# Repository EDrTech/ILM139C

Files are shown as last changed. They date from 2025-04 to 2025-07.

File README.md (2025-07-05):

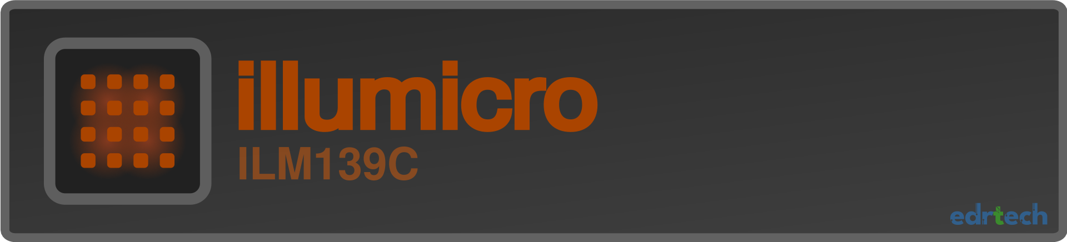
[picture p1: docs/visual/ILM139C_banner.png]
Banner

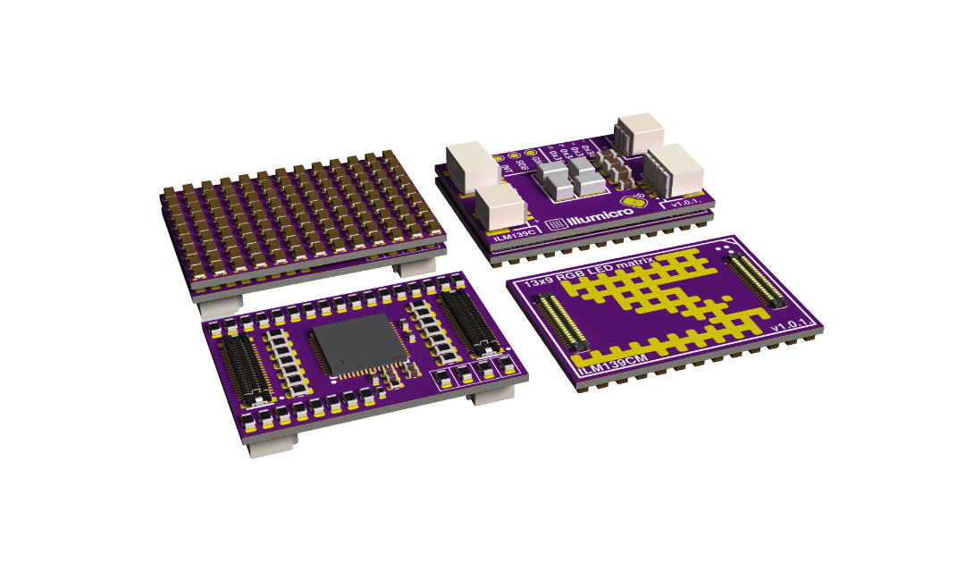
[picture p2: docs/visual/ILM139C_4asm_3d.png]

&nbsp;
###### <sub>Quick access</sub>
---------------------------------------------------------------------------------

<p align="center">
  
  
  
  
</p>

---------------------------------------------------------------------------------
&nbsp;
&nbsp;
&nbsp;
---------------------------------------------------------------------------------
> [!WARNING]
> <p>
> This project is currently under active development. It is experimental, and may not function as intended. The source files might not exactly match tested hardware if you can see this message. Use at your own risk.
><br clear="right"/>
></p>

---------------------------------------------------------------------------------
# Illumicro ILM139C 13x9 RGB LED matrix

<p align="center">
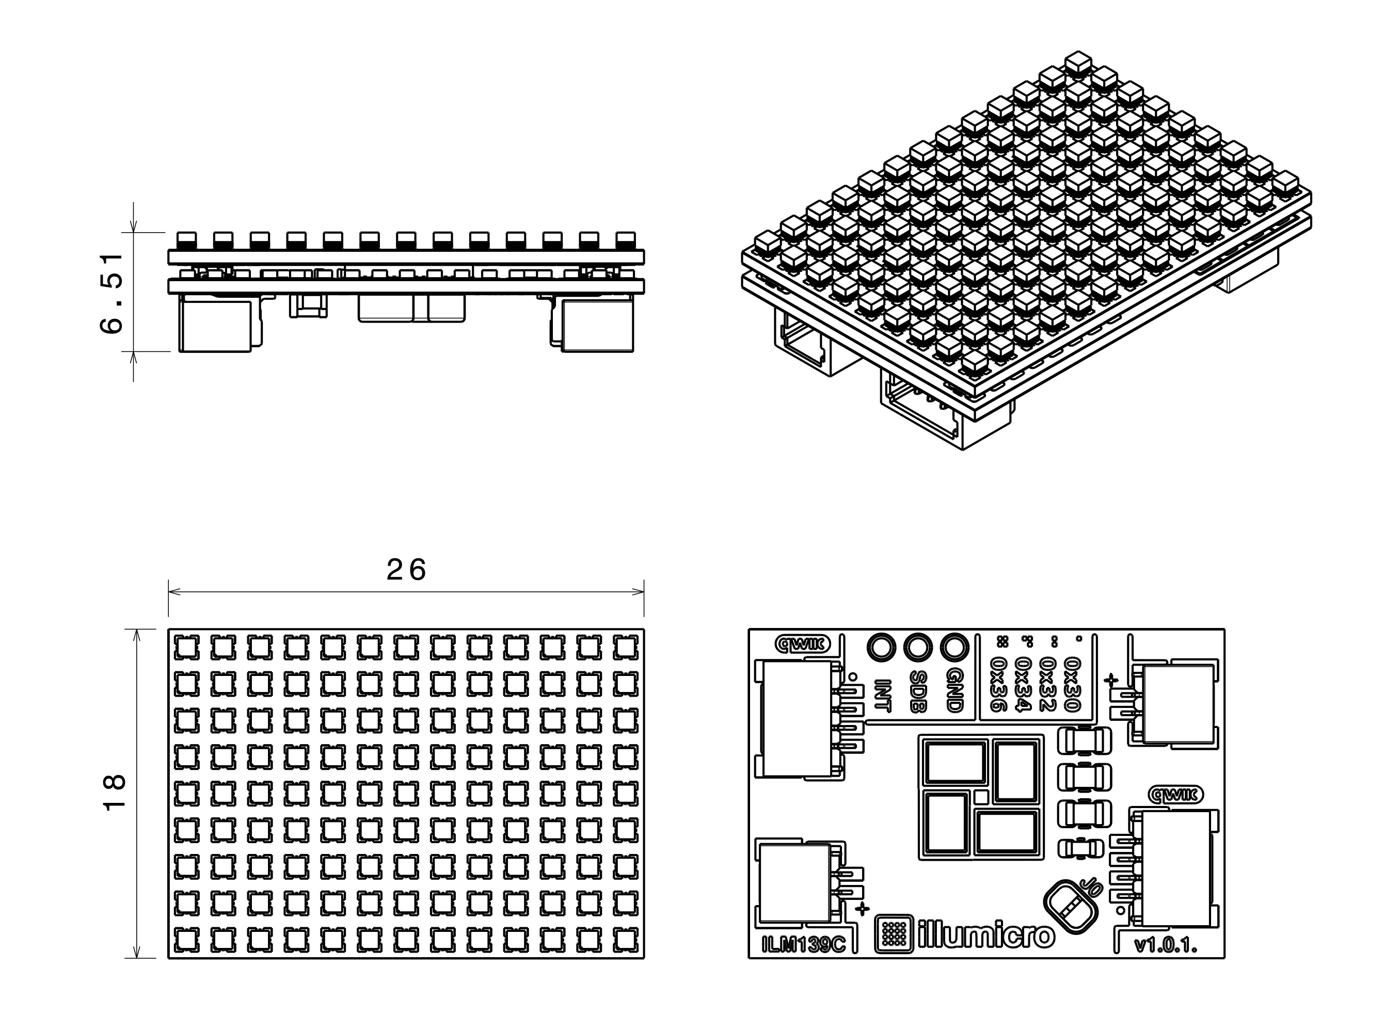
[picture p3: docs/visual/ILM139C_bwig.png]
  
</p>
ILM139C Is an RGB LED module with a matrix of 13x9 RGB LEDs.
It is based on the IS31FL3741A LED matrix driver, which provides an i2c interface for full control of
individual LEDs which is accessible with a standard QWIIC connector. 
QWIIC Connector allows for up to 4 modules to be connected together on a single i2c bus.
Small form factor of 26mm*18mm and 2mm pitch of LEDs allows for creating small 
high density and high brightness displays.

https://github.com/user-attachments/assets/0ada246c-68c4-4b34-9f10-4a2aee3bf7c3

&nbsp;
&nbsp;
&nbsp;
&nbsp;
&nbsp;
&nbsp;
&nbsp;
&nbsp;
&nbsp;
&nbsp;

# Features
&nbsp;
&nbsp;
&nbsp;
&nbsp;
&nbsp;
<p>

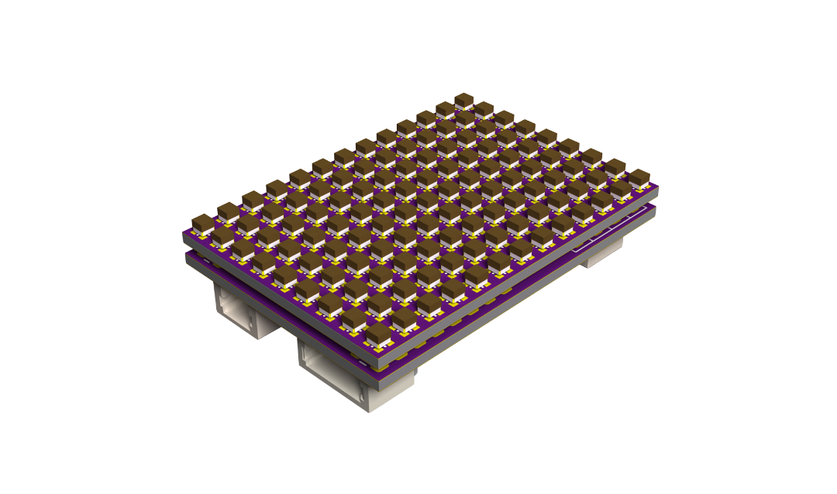
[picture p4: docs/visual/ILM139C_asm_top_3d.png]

  
- Very small footprint of 26mm*18mm
- 13x9 RBG LED matrix
- 1mm*1mm LEDs, with 2mm pitch
- IS31FL3741A Driver
- 2.7V~5.5V Operating voltage
- QWIIC Connector
- Selectable i2c address
- Removable driver/matrix boards
- Separate power supply connector
  
</p>
&nbsp;
&nbsp;
&nbsp;

# ILM139C Module pinout

<p align="center">
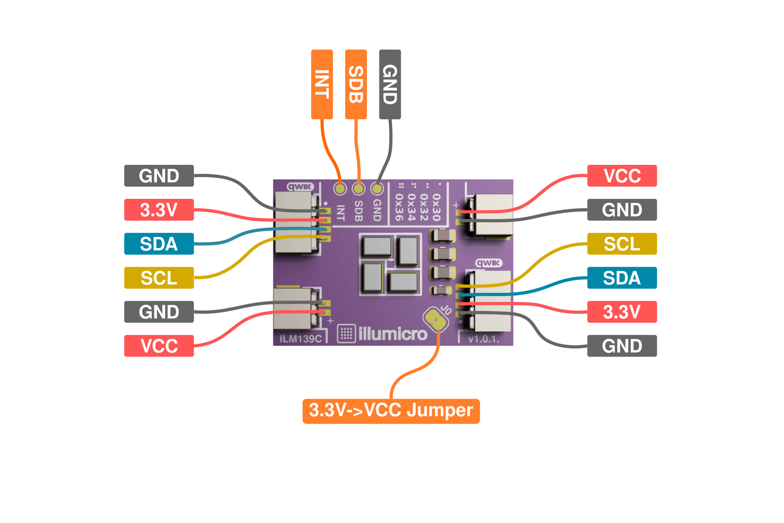
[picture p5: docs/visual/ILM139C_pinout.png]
  
</p>

---------------------------------------------------------------------------------

# Installation and set up

Connect QWIIC cable to one of the available connectors on the bottom of the module. If you want to power the module over QWIIC, the jumper resistor should be soldered on the bottom of the module. If the jumper is present, DO NOT connect external power supply as it will short to 3.3V of the QWIIC!
The module can be programmed over i2c, a library is currently under development to allow straightforward integration with and i2c capable device.

&nbsp;
&nbsp;
&nbsp;

illumicro Series

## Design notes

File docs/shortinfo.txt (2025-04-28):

ILM139C (ILM139CM + ILM139CD) 13X9 RGB LED matrix, 1mm*1mm RGB leds, 2mm pitch, IS31FL3741A driver, compact package 26mm*18mm*3.2mm assembled, 2x qwiic optional connector, 2x power optional connector, i2c address switching using jumper resistors, jumper for qwiic 3v3 to vcc jump, 2.7V-5.5V input voltage, interrupt and shutdown pins broken out, seamlessly stackable design, up to four ILM139C assemblies on single i2c bus, individual LED PWM control, adjustable current, LED open/short software detection, 1MHz i2c, LED matrix is removable, low profile connectors (0.8mm mating height) between matrix and driver boards

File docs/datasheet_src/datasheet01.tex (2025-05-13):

% === START TEMPLATE WITH CONFIGURABLE WATERMARK POSITION ===
\documentclass[10pt]{article}
\usepackage[utf8]{inputenc}
\usepackage[left=50pt,right=50pt,top=100pt,bottom=100pt]{geometry}
\usepackage[T1]{fontenc}
\usepackage{lmodern}
\usepackage[hidelinks]{hyperref}
\usepackage{graphicx}
\usepackage[table]{xcolor}
\usepackage{transparent}
\usepackage{tabularx}
\usepackage{stackengine}
\usepackage{mwe}
\usepackage{tocloft}
\usepackage[hypcap=false,font=small]{caption}
\usepackage{capt-of}
\usepackage{multicol}
\usepackage{ragged2e}
\usepackage{titlesec}
\usepackage{fancyhdr}
\usepackage{etoolbox}
\usepackage{eso-pic}

% === User-Configurable Variables ===
\newcommand{\ProductName}{ILM139C RGB LED Matrix}
\newcommand{\ProductNameShort}{ILM139C}
\newcommand{\WebsiteLinkText}{www.rudectech.com}
\newcommand{\ReleaseDate}{2025-05-13}
\newcommand{\Revision}{Rev.\ 1.0}

% === Watermark Variables ===
\newcommand{\WatermarkPath}{example-image}
\newcommand{\WatermarkScale}{0}
\newcommand{\WatermarkAngle}{45}
\newcommand{\WatermarkOpacity}{0.1}
\newcommand{\WatermarkPosX}{0.1\paperwidth}
\newcommand{\WatermarkPosY}{0.1\paperheight}

% Place watermark
\AddToShipoutPictureBG{%
	\AtPageLowerLeft{%
		\raisebox{\WatermarkPosY}[0pt][0pt]{%
			\makebox[\WatermarkPosX][l]{%
				\transparent{\WatermarkOpacity}%
				%
			}%
		}%
	}%
}

% TOC config
\renewcommand{\contentsname}{Table of Contents}
\setcounter{tocdepth}{2}
\renewcommand{\cftdotsep}{1.5}
\renewcommand{\cftsecleader}{\cftdotfill{\cftdotsep}}
\renewcommand{\cftsubsecleader}{\cftdotfill{\cftdotsep}}
\setlength{\cftbeforesecskip}{0.5em}
\setlength{\cftbeforesubsecskip}{0.5em}

\renewcommand{\familydefault}{\sfdefault}

\pagestyle{fancy}
\fancyhf{}
\renewcommand{\headrulewidth}{0.4pt}
\renewcommand{\footrulewidth}{0.4pt}
\setlength{\headheight}{60pt}
\setlength{\headsep}{10pt}
\setlength{\footskip}{50pt}
\lhead{}
\rhead{%
	\\[-0.5em]
	{\scriptsize\textcolor{gray!50}{\WebsiteLinkText}}%
}
\fancyfoot[L]{\footnotesize\textcolor{gray!50}{{\ProductNameShort} Datasheet}}%
\fancyfoot[C]{\footnotesize\textcolor{gray!50}{\Revision}}
\fancyfoot[R]{\footnotesize\textcolor{gray!50}{\thepage}}

\fancypagestyle{plain}{%
	\fancyhf{}%
	\lhead{\Large\textbf{\ProductNameShort}}%
	\rhead{%
		\\[-0.5em]
		{\scriptsize\textcolor{gray!50}{\WebsiteLinkText}}%
	}%
\fancyfoot[L]{\footnotesize\textcolor{gray!50}{{\ProductNameShort} Datasheet}}%
	\fancyfoot[C]{\footnotesize\textcolor{gray!50}{\Revision}}%
	\fancyfoot[R]{\footnotesize\textcolor{gray!50}{\thepage}}%
	\renewcommand{\headrulewidth}{0.4pt}%
	\renewcommand{\footrulewidth}{0.4pt}%
}

\setcounter{secnumdepth}{3}
\renewcommand{\thesubsection}{\arabic{section}.\arabic{subsection}}
\renewcommand{\thesubsubsection}{\arabic{section}.\arabic{subsection}.\arabic{subsubsection}}
\titleformat{\subsection}[hang]
{\large\bfseries}{\thesubsection}{1em}{}
[\color{gray!30}\rule{\textwidth}{0.4pt}]
\titlespacing*{\subsection}{0pt}{1.5\baselineskip}{1\baselineskip}
\newcommand{\sectionbreak}{\clearpage}

\begin{document}
	\flushbottom
	\begin{center}
		{\LARGE\bfseries \ProductName\par}
		\vspace{1ex}
		{\normalsize Datasheet\par}
	\end{center}
	\vspace{2\baselineskip}
	
	\noindent
	\begin{minipage}[t]{0.45\textwidth}
		\section{Features}\label{sec:features}
		\vspace{\baselineskip}
		\begin{itemize}
			\item 13x9 RGB LED matrix
			\item Small 26mm*18mm Footprint
			\item 2mm pitch, 1mm x 1mm LEDs
			\item Based on IS31FL3741A LED driver
			\item Individual LED PWM control
			\item 2.7V–5.5V input voltage range
			\item Qwiic-compatible connector
			\item Optional 2-pin power connector
			\item I\textsuperscript{2}C address selection via jumpers
		\end{itemize}
	\end{minipage}
	\hfill
	\begin{minipage}[t]{0.5\textwidth}
		\section{Description}\label{sec:desc}
		\vspace{\baselineskip}
		This compact RGB LED matrix module integrates a high-density 13×9 full-color LED array with an onboard IS31FL3741 driver IC. Designed for seamless integration into I2C-based systems, the module supports individual PWM control of all 351 LEDs and features a robust, stackable form factor suitable for embedded, wearable, and interactive display applications.
		
	\begin{center}
		\vskip 30px
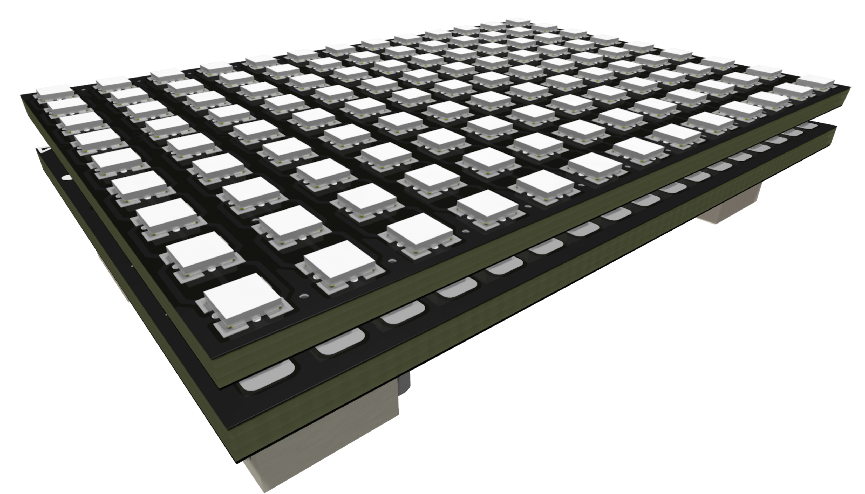
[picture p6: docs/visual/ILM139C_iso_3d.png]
	
	\captionof{figure}{Module Overview}
	\label{fig:component}
\end{center}

	\end{minipage}
	
	\section*{\contentsname}
	\begin{multicols}{2}
		{\let\oldcontentsname\contentsname
			\renewcommand{\contentsname}{}
			\tableofcontents
			\let\contentsname\oldcontentsname}
	\end{multicols}
	
	\vspace{1em}
	\noindent\textbf{Revision History}\par
	\begin{tabularx}{\textwidth}{|l|X|}
		\hline
		\rowcolor{gray!25}\textbf{Date} & \textbf{Description} \\ \hline
		\ReleaseDate & Initial release \\ \hline
	\end{tabularx}
	\captionof{table}{Revision History}\label{tab:rev}
	
	\sectionbreak
	
	\section{Device Overview}\label{sec:overview}
	\subsection{Part Number Options}\label{sec:overview.1}
	\begin{tabularx}{\textwidth}{|X|X|X|}
		\hline
		\rowcolor{gray!25}\textbf{PART NUMBER} & \textbf{PACKAGE} & \textbf{DESCRIPTION} \\ \hline
		ILM139C & 26mm × 18mm × 3.2mm & Complete module \\ \hline
		ILM139CD & Driver board & IS31FL3741A module \\ \hline
		ILM139CM & LED matrix board & 13x9 RGB LED matrix module \\ \hline
	\end{tabularx}
	\captionof{table}{Part Number Options}\label{tab:overview1}
	\sectionbreak
	\subsection{Pin Configuration and Functions}\label{sec:overview.2}
	\begin{tabularx}{\textwidth}{|l|X|}
		\hline
		\rowcolor{gray!25}\textbf{Label} & \textbf{Description} \\ \hline
		SDA & I\textsuperscript{2}C data \\ \hline
		SCL & I\textsuperscript{2}C clock \\ \hline
		INT & Interrupt output \\ \hline
		SDB & Shutdown \\ \hline
		3.3V & QWIIC 3.3V \\ \hline
		VCC & 2.7V~5.5V Power supply input \\ \hline
		GND & Ground \\ \hline
		3.3V->VCC Jumper & 0603 SMD Jumper. If present, VCC=QWIIC 3.3V \\ \hline
	\end{tabularx}
	\captionof{table}{Pin description}\label{tab:rev}
	\begin{center}
		\captionof{figure}{Module Pins}\label{fig:component}
	\end{center}

	\sectionbreak
	
	\section{Specifications}\label{sec:specs}
	\subsection{Absolute Maximum Ratings}\label{sec:specs.1}
	\begin{tabularx}{\textwidth}{|X|X|X|}
		\hline
		\rowcolor{gray!25}\textbf{PARAMETER} & \textbf{MAX RATING} & \textbf{UNIT} \\ \hline
		Supply Voltage (VCC) & 6.0 & V \\ \hline
		Storage Temperature & -40 to 85 & °C \\ \hline
	\end{tabularx}
	\captionof{table}{Absolute Maximum Ratings}\label{tab:amax}
	
	\subsection{Recommended Operating Conditions}\label{sec:specs.2}
	\begin{tabularx}{\textwidth}{|X|X|X|}
		\hline
		\rowcolor{gray!25}\textbf{PARAMETER} & \textbf{TYPICAL} & \textbf{UNIT} \\ \hline
		Input Voltage & 3.3 – 5.0 & V \\ \hline
		Operating Temp. Range & -20 to +70 & °C \\ \hline
	\end{tabularx}
	\captionof{table}{Recommended Operating Conditions}\label{tab:opcond}
	
	\subsection{Electrical Characteristics}\label{sec:specs.3}
	\begin{tabularx}{\textwidth}{|X|X|X|}
		\hline
		\rowcolor{gray!25}\textbf{PARAMETER} & \textbf{TYPICAL} & \textbf{UNIT} \\ \hline
		I\textsuperscript{2}C Clock Rate & 1000 & kHz \\ \hline
		LED Current (adjustable) & 1–30 & mA \\ \hline
	\end{tabularx}
	\captionof{table}{Electrical Characteristics}\label{tab:elec}
	
	\sectionbreak
	
	\section{Feature Description}\label{sec:features_desc}
	\subsection{Modular Construction}
	The ILM139C is split into two boards, simplifying repairs and customization. The LED matrix board can be removed or replaced independently of the driver.
	
	\subsection{Qwiic Interface and Power Options}
	The Qwiic system provides a 4-pin JST-SH connector for quick daisy-chaining of I\textsuperscript{2}C devices. Power is typically supplied via Qwiic (3.3V). A solderable SMD jumper on the back of the driver board connects 3.3V from Qwiic to the VCC rail.
	
	\textbf{Important:} If the jumper is soldered, do not connect another external power supply to the 2-pin VCC/GND connector to avoid damaging the module.
	
	If you wish to use external power (3.3–5V), leave the jumper open and connect a regulated supply to the 2-pin header.
	
	\subsection{LED Control and Flexibility}
	Each LED can be controlled independently for color and brightness. The IS31FL3741A handles PWM, current control, and I\textsuperscript{2}C interfacing. For advanced settings, refer to the \underline{\href{https://www.lumissil.com/assets/pdf/core/IS31FL3741A_DS.pdf}{IS31FL3741A datasheet}}
	
	\sectionbreak
	
	\section{Getting Started}\label{sec:getting}
	\subsection{Using Arduino}
	To use ILM139C with Arduino:
	
	\begin{enumerate}
		\item Connect the Qwiic cable to your controller.
		\item Solder the SMD jumper on the ILM139CD driver board if using Qwiic power.
		\item Install the library: \texttt{https://example.com/ILM139C-Arduino}
		\item Upload the basic example sketch.
	\end{enumerate}
	
	\texttt{
		Wire.begin(); \\
		ILM139C.begin(); \\
		ILM139C.setPixel(5, 3, 255, 0, 0);
	}
	
	\sectionbreak
	
	\section{Part numbering Information}\label{sec:order}
	\begin{tabularx}{\textwidth}{|X|X|X|}
		\hline
		\rowcolor{gray!25}\textbf{PART NUMBER} & \textbf{ORDER CODE} & \textbf{DESCRIPTION} \\ \hline
		ILM139C & ILM139C-BASE & Full RGB Matrix Module \\ \hline
		ILM139CD & ILM139C-DRV & Driver Moduleonly \\ \hline
		ILM139CM & ILM139C-MTX & LED Matrix only \\ \hline
	\end{tabularx}
	\captionof{table}{Ordering Information}\label{tab:order}
	
\end{document}

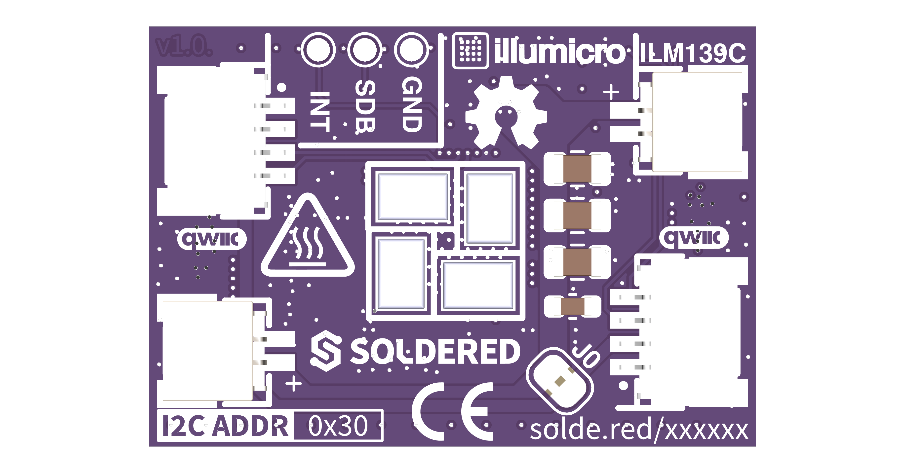
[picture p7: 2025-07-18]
pcb_src/v1.0.0/ILM139C_driver/ILM139CM_designp.png

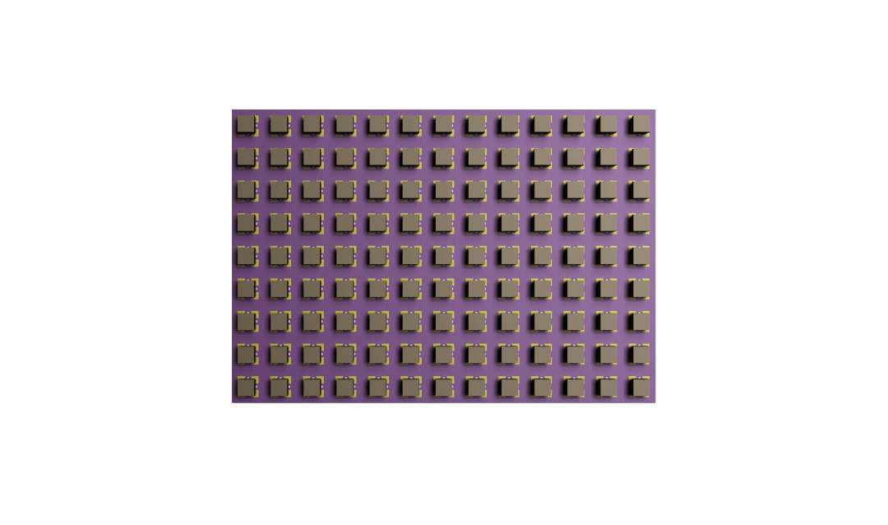
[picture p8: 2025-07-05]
docs/visual/ILM139C_top.png

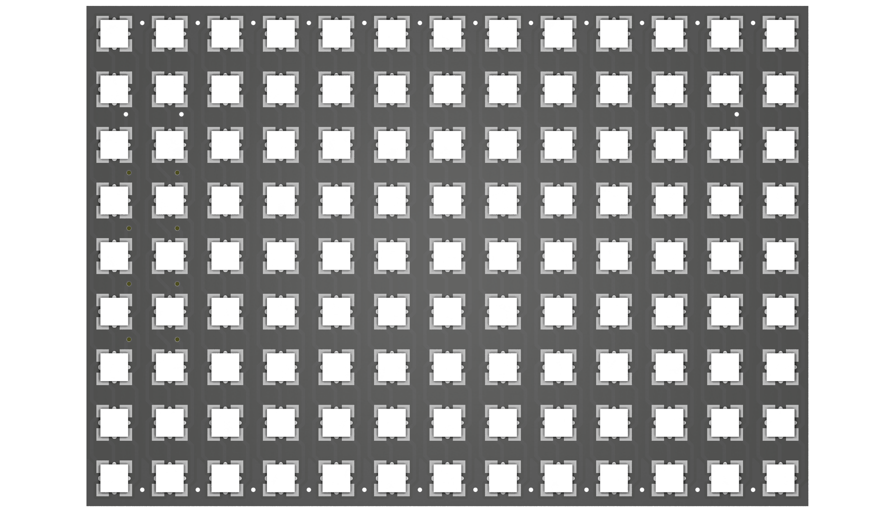
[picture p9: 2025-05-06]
docs/visual/ILM139CM_top.png

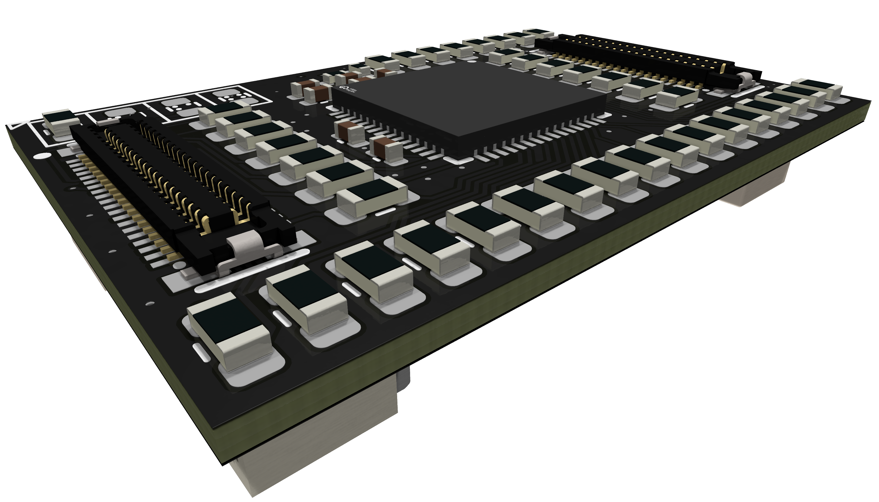
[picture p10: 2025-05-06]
docs/visual/ILM139CD_iso_3d_top.png

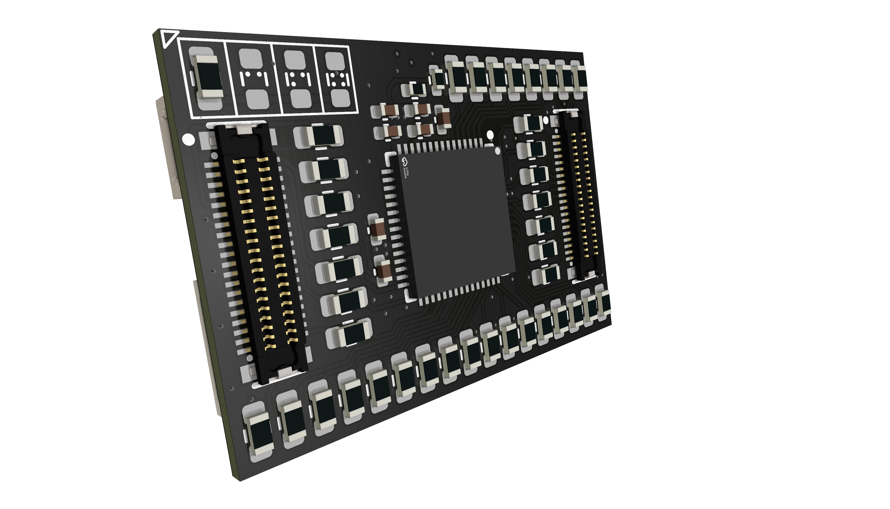
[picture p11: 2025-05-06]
docs/visual/ILM139CD_vert_3d_top.png

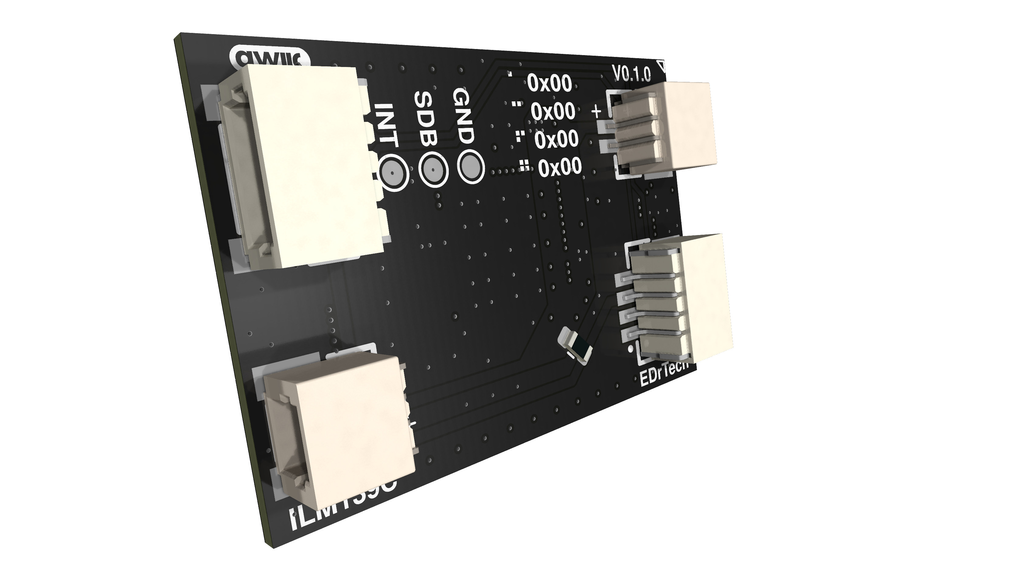
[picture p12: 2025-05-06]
docs/visual/ILM139CD_vert_3d_bot.png

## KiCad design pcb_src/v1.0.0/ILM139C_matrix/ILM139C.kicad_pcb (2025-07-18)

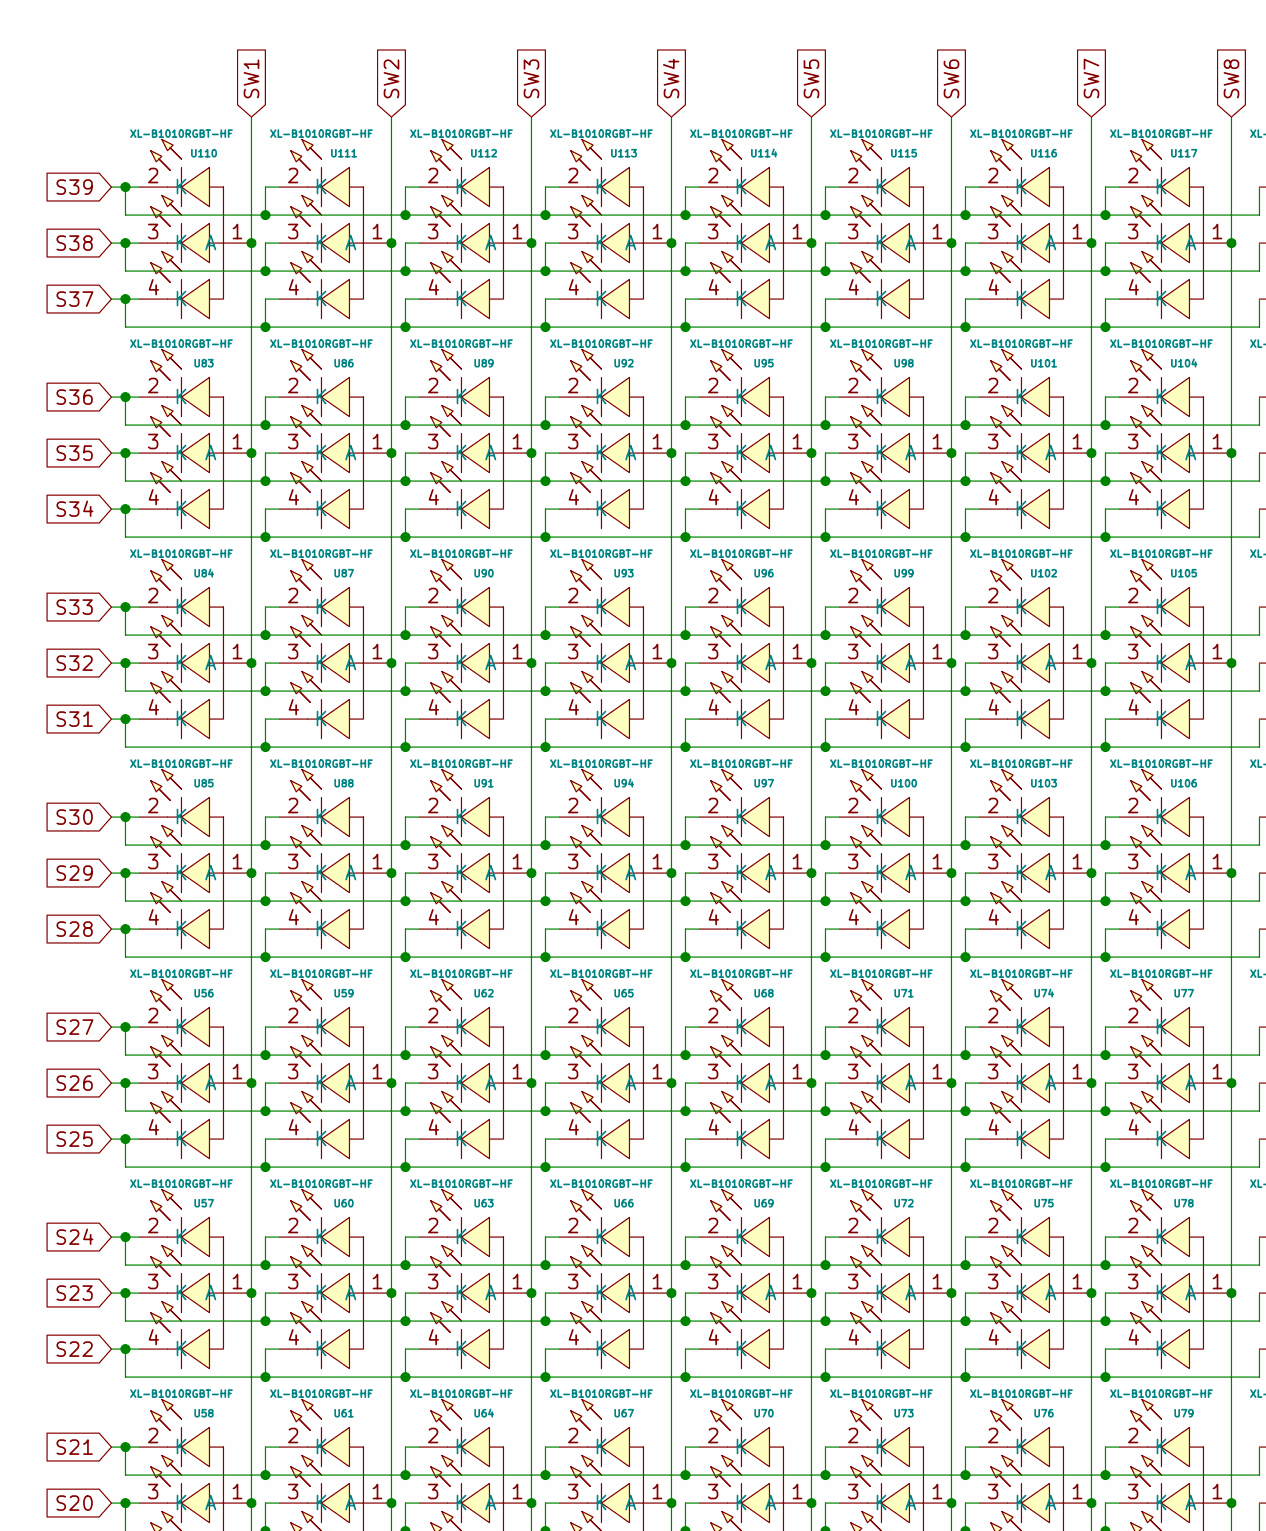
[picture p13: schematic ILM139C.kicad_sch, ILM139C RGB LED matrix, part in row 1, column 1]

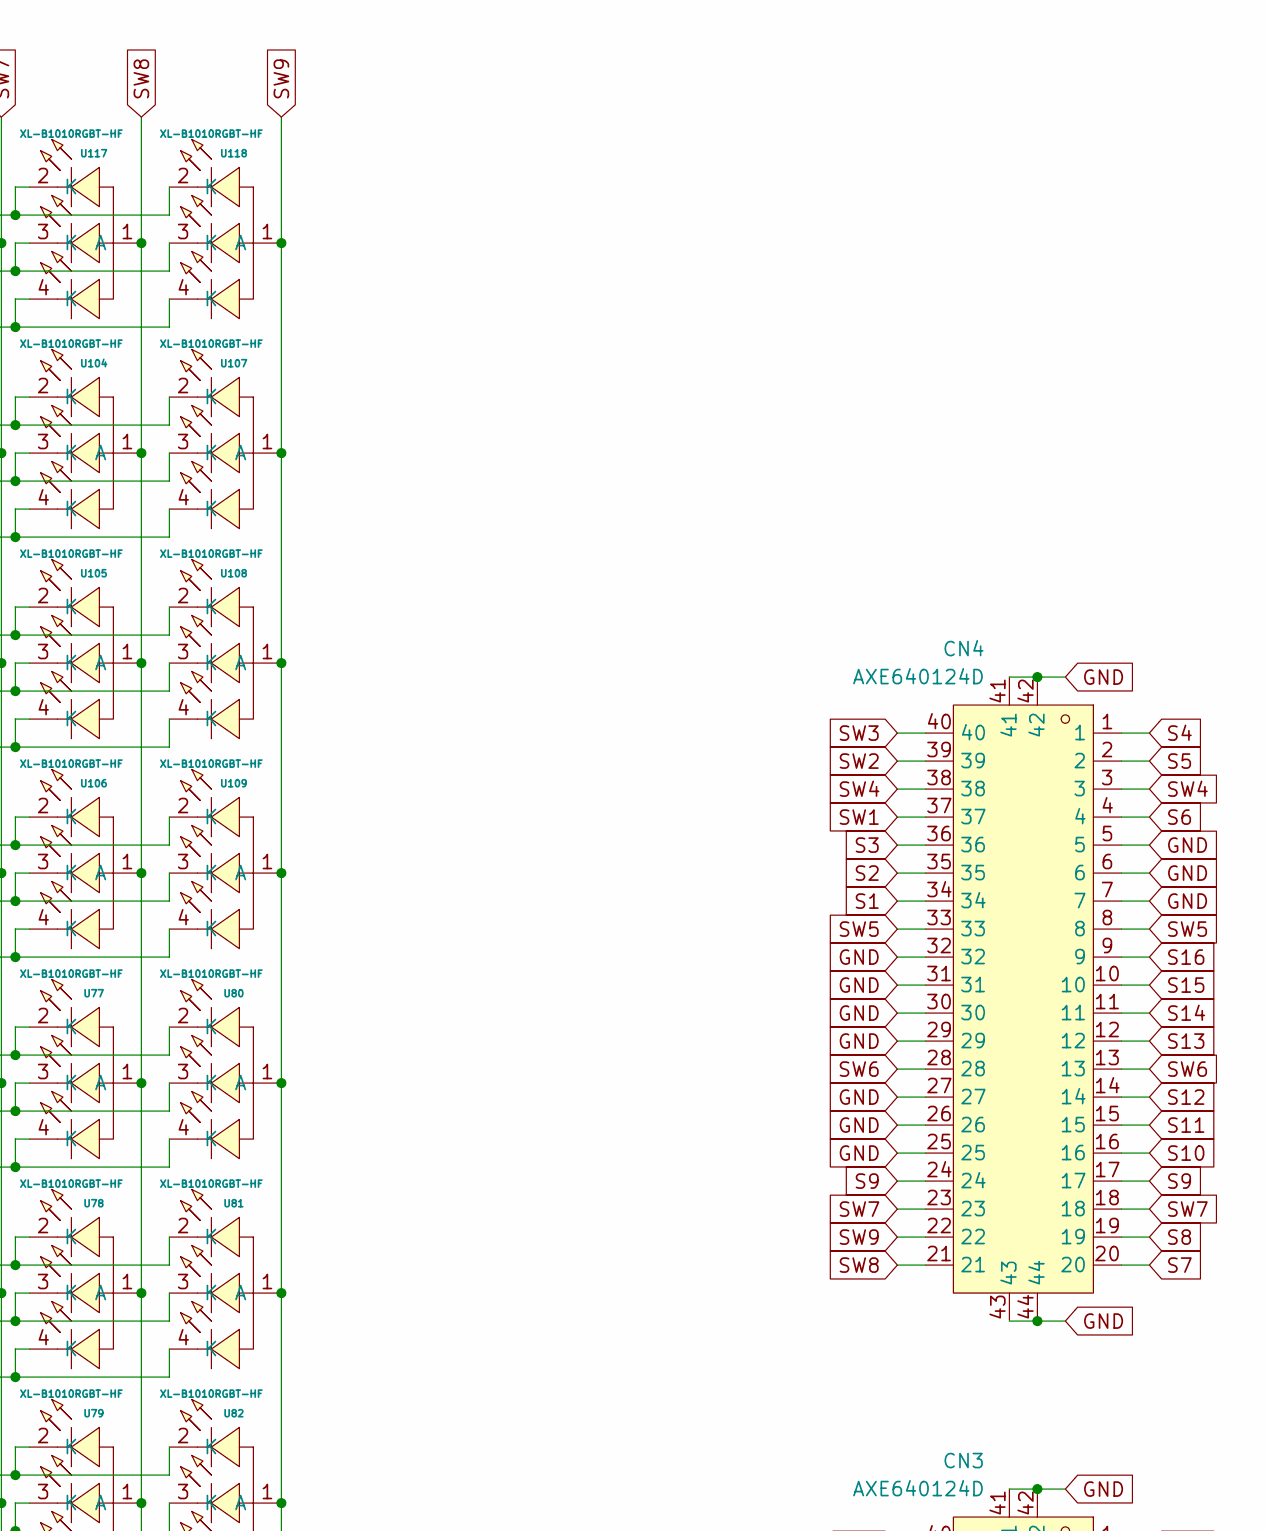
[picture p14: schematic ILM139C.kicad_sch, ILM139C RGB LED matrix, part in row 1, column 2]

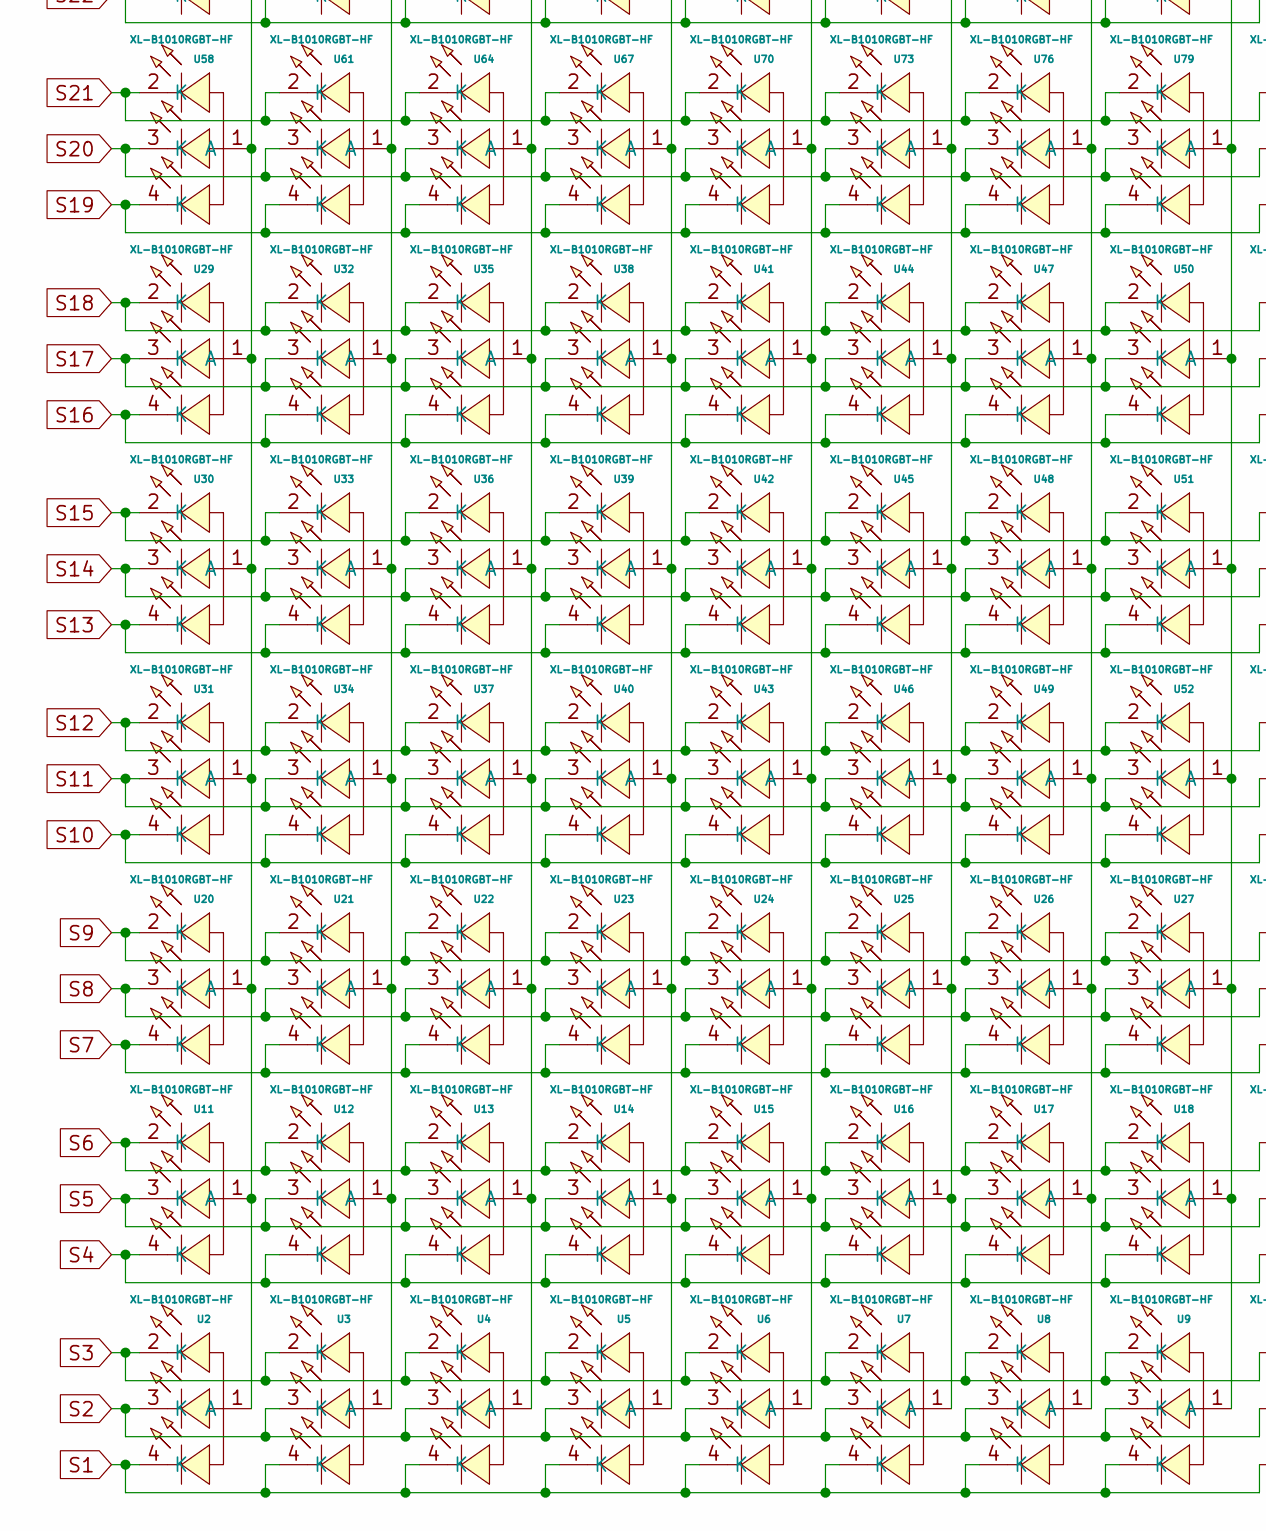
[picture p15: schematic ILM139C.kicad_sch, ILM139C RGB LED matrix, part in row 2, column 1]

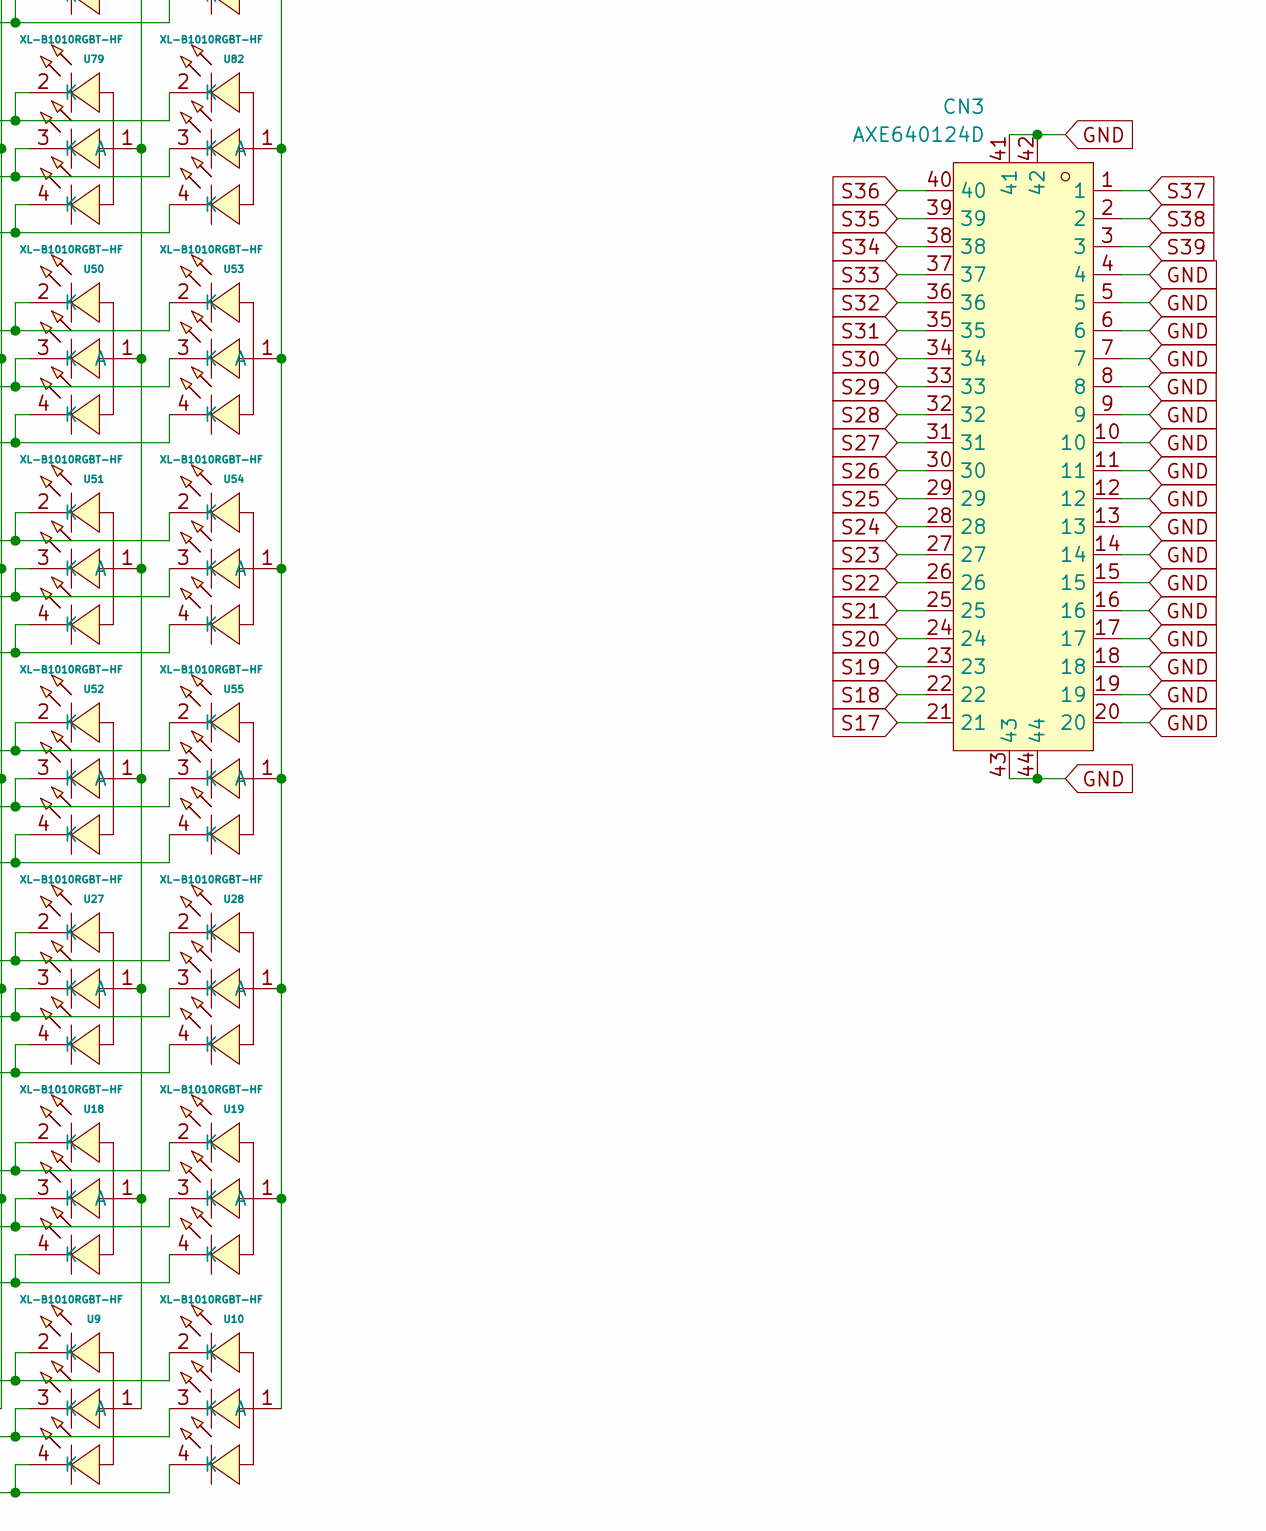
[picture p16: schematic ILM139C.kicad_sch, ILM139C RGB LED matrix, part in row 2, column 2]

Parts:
CN3, CN4: AXE640124D; CONN-SMD_40P-P0.40_OK-14GM040-04; LCSC Part C5128265
U2, U3, U4, U5, U6, U7, U8, U9, U10, U11, U12, U13, U14, U15, U16, U17, U18, U19, U20, U21, U22, U23, U24, U25, U26, U27, U28, U29, U30, U31, U32, U33, U34, U35, U36, U37, U38, U39, U40, U41, U42, U43, U44, U45, U46, U47, U48, U49, U50, U51, U52, U53, U54, U55, U56, U57, U58, U59, U60, U61, U62, U63, U64, U65, U66, U67, U68, U69, U70, U71, U72, U73, U74, U75, U76, U77, U78, U79, U80, U81, U82, U83, U84, U85, U86, U87, U88, U89, U90, U91, U92, U93, U94, U95, U96, U97, U98, U99, U100, U101, U102, U103, U104, U105, U106, U107, U108, U109, U110, U111, U112, U113, U114, U115, U116, U117, U118: XL-B1010RGBT-HF; LED-SMD_4P-L1.0-W1.0-TR_1; LCSC Part C22464515

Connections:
GND: CN3.4, CN3.5, CN3.6, CN3.7, CN3.8, CN3.9, CN3.10, CN3.11, CN3.12, CN3.13, CN3.14, CN3.15, CN3.16, CN3.17, CN3.18, CN3.19, CN3.20, CN3.41, CN3.42, CN3.43, CN3.44, CN4.5, CN4.6, CN4.7, CN4.25, CN4.26, CN4.27, CN4.29, CN4.30, CN4.31, CN4.32, CN4.41, CN4.42, CN4.43, CN4.44
S1: CN4.34, U2.4 (K), U3.4 (K), U4.4 (K), U5.4 (K), U6.4 (K), U7.4 (K), U8.4 (K), U9.4 (K), U10.4 (K)
S2: CN4.35, U2.3 (K), U3.3 (K), U4.3 (K), U5.3 (K), U6.3 (K), U7.3 (K), U8.3 (K), U9.3 (K), U10.3 (K)
S3: CN4.36, U2.2 (K), U3.2 (K), U4.2 (K), U5.2 (K), U6.2 (K), U7.2 (K), U8.2 (K), U9.2 (K), U10.2 (K)
S4: CN4.1, U11.4 (K), U12.4 (K), U13.4 (K), U14.4 (K), U15.4 (K), U16.4 (K), U17.4 (K), U18.4 (K), U19.4 (K)
S5: CN4.2, U11.3 (K), U12.3 (K), U13.3 (K), U14.3 (K), U15.3 (K), U16.3 (K), U17.3 (K), U18.3 (K), U19.3 (K)
S6: CN4.4, U11.2 (K), U12.2 (K), U13.2 (K), U14.2 (K), U15.2 (K), U16.2 (K), U17.2 (K), U18.2 (K), U19.2 (K)
S7: CN4.20, U20.4 (K), U21.4 (K), U22.4 (K), U23.4 (K), U24.4 (K), U25.4 (K), U26.4 (K), U27.4 (K), U28.4 (K)
S8: CN4.19, U20.3 (K), U21.3 (K), U22.3 (K), U23.3 (K), U24.3 (K), U25.3 (K), U26.3 (K), U27.3 (K), U28.3 (K)
S9: CN4.17, CN4.24, U20.2 (K), U21.2 (K), U22.2 (K), U23.2 (K), U24.2 (K), U25.2 (K), U26.2 (K), U27.2 (K), U28.2 (K)
S10: CN4.16, U31.4 (K), U34.4 (K), U37.4 (K), U40.4 (K), U43.4 (K), U46.4 (K), U49.4 (K), U52.4 (K), U55.4 (K)
S11: CN4.15, U31.3 (K), U34.3 (K), U37.3 (K), U40.3 (K), U43.3 (K), U46.3 (K), U49.3 (K), U52.3 (K), U55.3 (K)
S12: CN4.14, U31.2 (K), U34.2 (K), U37.2 (K), U40.2 (K), U43.2 (K), U46.2 (K), U49.2 (K), U52.2 (K), U55.2 (K)
S13: CN4.12, U30.4 (K), U33.4 (K), U36.4 (K), U39.4 (K), U42.4 (K), U45.4 (K), U48.4 (K), U51.4 (K), U54.4 (K)
S14: CN4.11, U30.3 (K), U33.3 (K), U36.3 (K), U39.3 (K), U42.3 (K), U45.3 (K), U48.3 (K), U51.3 (K), U54.3 (K)
S15: CN4.10, U30.2 (K), U33.2 (K), U36.2 (K), U39.2 (K), U42.2 (K), U45.2 (K), U48.2 (K), U51.2 (K), U54.2 (K)
S16: CN4.9, U29.4 (K), U32.4 (K), U35.4 (K), U38.4 (K), U41.4 (K), U44.4 (K), U47.4 (K), U50.4 (K), U53.4 (K)
S17: CN3.21, U29.3 (K), U32.3 (K), U35.3 (K), U38.3 (K), U41.3 (K), U44.3 (K), U47.3 (K), U50.3 (K), U53.3 (K)
S18: CN3.22, U29.2 (K), U32.2 (K), U35.2 (K), U38.2 (K), U41.2 (K), U44.2 (K), U47.2 (K), U50.2 (K), U53.2 (K)
S19: CN3.23, U58.4 (K), U61.4 (K), U64.4 (K), U67.4 (K), U70.4 (K), U73.4 (K), U76.4 (K), U79.4 (K), U82.4 (K)
S20: CN3.24, U58.3 (K), U61.3 (K), U64.3 (K), U67.3 (K), U70.3 (K), U73.3 (K), U76.3 (K), U79.3 (K), U82.3 (K)
S21: CN3.25, U58.2 (K), U61.2 (K), U64.2 (K), U67.2 (K), U70.2 (K), U73.2 (K), U76.2 (K), U79.2 (K), U82.2 (K)
S22: CN3.26, U57.4 (K), U60.4 (K), U63.4 (K), U66.4 (K), U69.4 (K), U72.4 (K), U75.4 (K), U78.4 (K), U81.4 (K)
S23: CN3.27, U57.3 (K), U60.3 (K), U63.3 (K), U66.3 (K), U69.3 (K), U72.3 (K), U75.3 (K), U78.3 (K), U81.3 (K)
S24: CN3.28, U57.2 (K), U60.2 (K), U63.2 (K), U66.2 (K), U69.2 (K), U72.2 (K), U75.2 (K), U78.2 (K), U81.2 (K)
S25: CN3.29, U56.4 (K), U59.4 (K), U62.4 (K), U65.4 (K), U68.4 (K), U71.4 (K), U74.4 (K), U77.4 (K), U80.4 (K)
S26: CN3.30, U56.3 (K), U59.3 (K), U62.3 (K), U65.3 (K), U68.3 (K), U71.3 (K), U74.3 (K), U77.3 (K), U80.3 (K)
S27: CN3.31, U56.2 (K), U59.2 (K), U62.2 (K), U65.2 (K), U68.2 (K), U71.2 (K), U74.2 (K), U77.2 (K), U80.2 (K)
S28: CN3.32, U85.4 (K), U88.4 (K), U91.4 (K), U94.4 (K), U97.4 (K), U100.4 (K), U103.4 (K), U106.4 (K), U109.4 (K)
S29: CN3.33, U85.3 (K), U88.3 (K), U91.3 (K), U94.3 (K), U97.3 (K), U100.3 (K), U103.3 (K), U106.3 (K), U109.3 (K)
S30: CN3.34, U85.2 (K), U88.2 (K), U91.2 (K), U94.2 (K), U97.2 (K), U100.2 (K), U103.2 (K), U106.2 (K), U109.2 (K)
S31: CN3.35, U84.4 (K), U87.4 (K), U90.4 (K), U93.4 (K), U96.4 (K), U99.4 (K), U102.4 (K), U105.4 (K), U108.4 (K)
S32: CN3.36, U84.3 (K), U87.3 (K), U90.3 (K), U93.3 (K), U96.3 (K), U99.3 (K), U102.3 (K), U105.3 (K), U108.3 (K)
S33: CN3.37, U84.2 (K), U87.2 (K), U90.2 (K), U93.2 (K), U96.2 (K), U99.2 (K), U102.2 (K), U105.2 (K), U108.2 (K)
S34: CN3.38, U83.4 (K), U86.4 (K), U89.4 (K), U92.4 (K), U95.4 (K), U98.4 (K), U101.4 (K), U104.4 (K), U107.4 (K)
S35: CN3.39, U83.3 (K), U86.3 (K), U89.3 (K), U92.3 (K), U95.3 (K), U98.3 (K), U101.3 (K), U104.3 (K), U107.3 (K)
S36: CN3.40, U83.2 (K), U86.2 (K), U89.2 (K), U92.2 (K), U95.2 (K), U98.2 (K), U101.2 (K), U104.2 (K), U107.2 (K)
S37: CN3.1, U110.4 (K), U111.4 (K), U112.4 (K), U113.4 (K), U114.4 (K), U115.4 (K), U116.4 (K), U117.4 (K), U118.4 (K)
S38: CN3.2, U110.3 (K), U111.3 (K), U112.3 (K), U113.3 (K), U114.3 (K), U115.3 (K), U116.3 (K), U117.3 (K), U118.3 (K)
S39: CN3.3, U110.2 (K), U111.2 (K), U112.2 (K), U113.2 (K), U114.2 (K), U115.2 (K), U116.2 (K), U117.2 (K), U118.2 (K)
SW1: CN4.37, U2.1 (A), U11.1 (A), U20.1 (A), U29.1 (A), U30.1 (A), U31.1 (A), U56.1 (A), U57.1 (A), U58.1 (A), U83.1 (A), U84.1 (A), U85.1 (A), U110.1 (A)
SW2: CN4.39, U3.1 (A), U12.1 (A), U21.1 (A), U32.1 (A), U33.1 (A), U34.1 (A), U59.1 (A), U60.1 (A), U61.1 (A), U86.1 (A), U87.1 (A), U88.1 (A), U111.1 (A)
SW3: CN4.40, U4.1 (A), U13.1 (A), U22.1 (A), U35.1 (A), U36.1 (A), U37.1 (A), U62.1 (A), U63.1 (A), U64.1 (A), U89.1 (A), U90.1 (A), U91.1 (A), U112.1 (A)
SW4: CN4.3, CN4.38, U5.1 (A), U14.1 (A), U23.1 (A), U38.1 (A), U39.1 (A), U40.1 (A), U65.1 (A), U66.1 (A), U67.1 (A), U92.1 (A), U93.1 (A), U94.1 (A), U113.1 (A)
SW5: CN4.8, CN4.33, U6.1 (A), U15.1 (A), U24.1 (A), U41.1 (A), U42.1 (A), U43.1 (A), U68.1 (A), U69.1 (A), U70.1 (A), U95.1 (A), U96.1 (A), U97.1 (A), U114.1 (A)
SW6: CN4.13, CN4.28, U7.1 (A), U16.1 (A), U25.1 (A), U44.1 (A), U45.1 (A), U46.1 (A), U71.1 (A), U72.1 (A), U73.1 (A), U98.1 (A), U99.1 (A), U100.1 (A), U115.1 (A)
SW7: CN4.18, CN4.23, U8.1 (A), U17.1 (A), U26.1 (A), U47.1 (A), U48.1 (A), U49.1 (A), U74.1 (A), U75.1 (A), U76.1 (A), U101.1 (A), U102.1 (A), U103.1 (A), U116.1 (A)
SW8: CN4.21, U9.1 (A), U18.1 (A), U27.1 (A), U50.1 (A), U51.1 (A), U52.1 (A), U77.1 (A), U78.1 (A), U79.1 (A), U104.1 (A), U105.1 (A), U106.1 (A), U117.1 (A)
SW9: CN4.22, U10.1 (A), U19.1 (A), U28.1 (A), U53.1 (A), U54.1 (A), U55.1 (A), U80.1 (A), U81.1 (A), U82.1 (A), U107.1 (A), U108.1 (A), U109.1 (A), U118.1 (A)

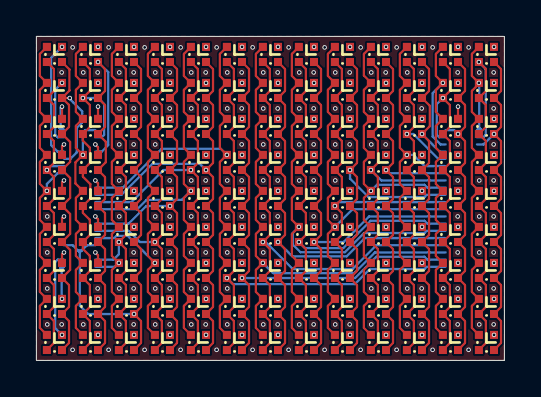
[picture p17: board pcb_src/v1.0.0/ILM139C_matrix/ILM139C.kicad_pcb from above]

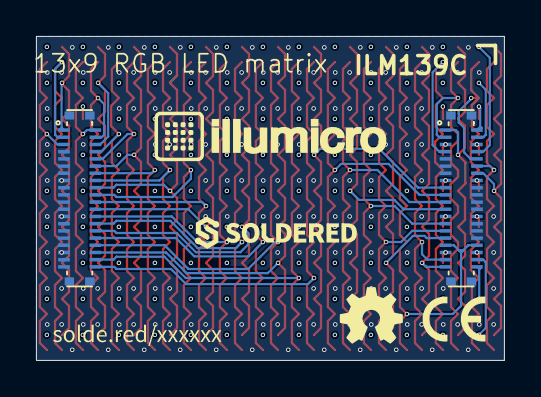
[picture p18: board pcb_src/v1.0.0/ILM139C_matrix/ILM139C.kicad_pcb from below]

Board: 4 copper layers, 26.0 x 18.0 mm, 120 parts (3 on the bottom side), 49 nets.

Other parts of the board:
kibuzzard-68775C53: G***; kibuzzard-68775C53

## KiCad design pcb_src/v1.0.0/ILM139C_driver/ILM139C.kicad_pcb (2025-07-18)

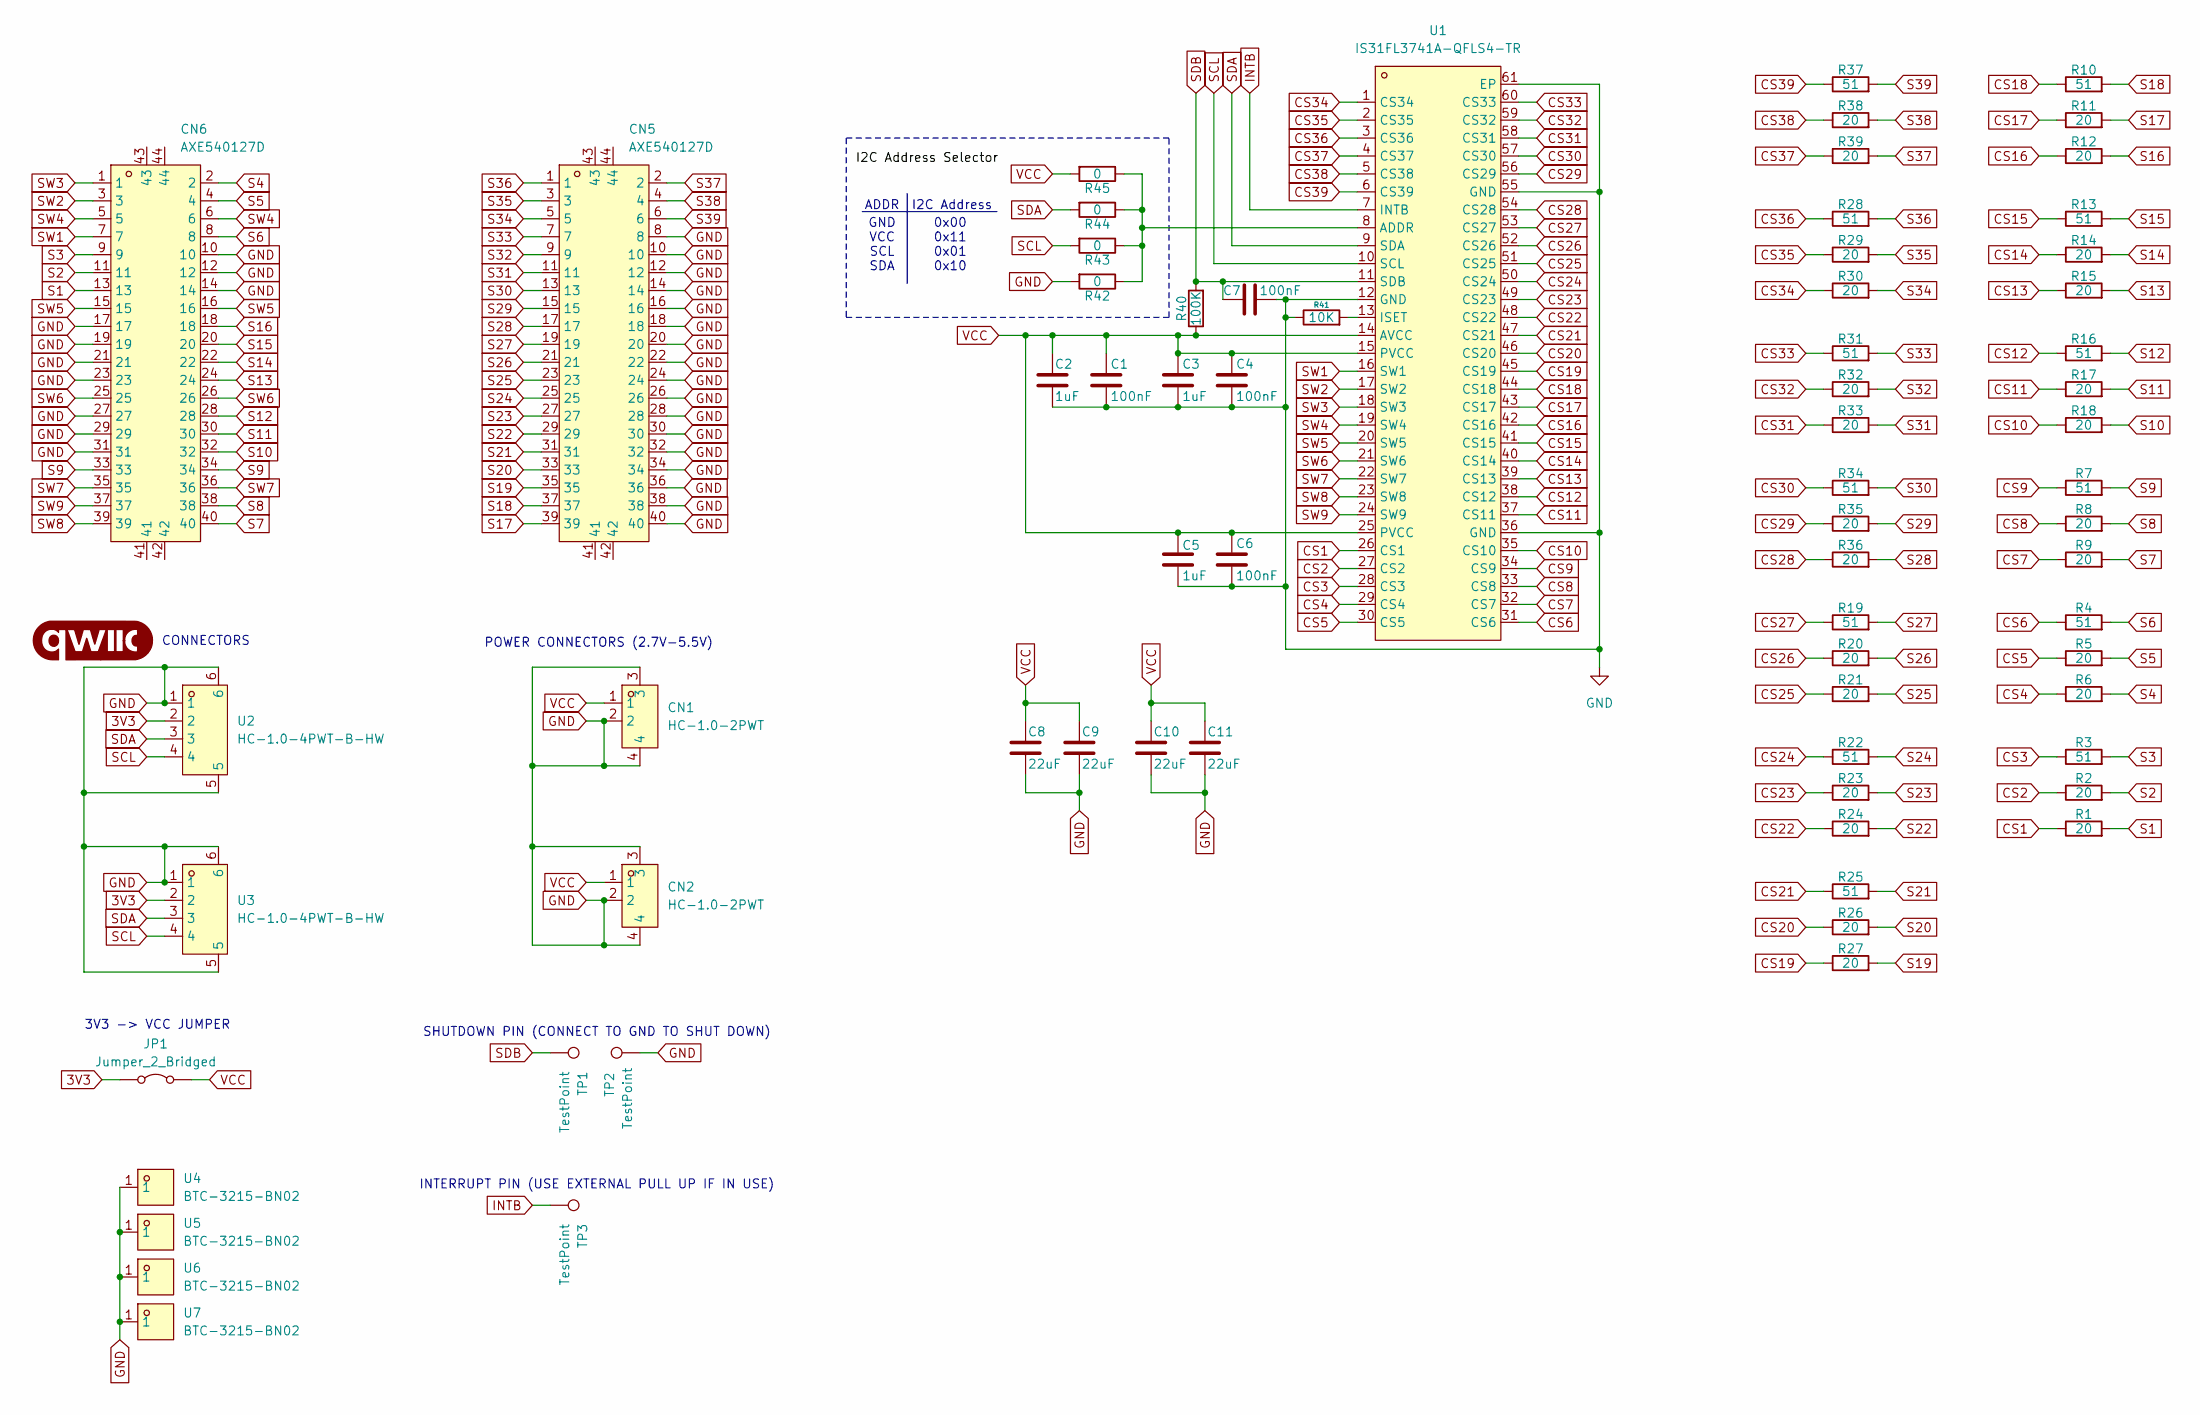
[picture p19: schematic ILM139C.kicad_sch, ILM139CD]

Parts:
C1, C4, C6, C7: 100nF; C_0402_1005Metric
C2, C3, C5: 1uF; C_0402_1005Metric
C8, C9, C10: 22uF; C_0805_2012Metric
C11: 22uF; C_0603_1608Metric
CN1, CN2: HC-1.0-2PWT; CONN-SMD_HC-1.0-2PWT; LCSC Part C2845361
CN5, CN6: AXE540127D; CONN-SMD_40P-P0.40_AXE540127D; LCSC Part C2982234
G1: qwiic_Logo; qwiic_3mm
JP1: Jumper_2_Bridged; SolderJumper-2_P1.3mm_Bridged2Bar_RoundedPad1.0x1.5mm
R1, R2, R5, R6, R8, R9, R11, R12, R14, R15, R17, R18, R20, R21, R23, R24, R26, R27, R29, R30, R32, R33, R35, R36, R38, R39: 20; R_0603_1608Metric
R3, R4, R7, R10, R13, R16, R19, R22, R25, R28, R31, R34, R37: 51; R_0603_1608Metric
R40: 100K; R_0402_1005Metric
R41: 10K; R_0402_1005Metric
R42, R43, R44, R45: 0; R_0603_1608Metric
TP1, TP2, TP3: TestPoint; TestPoint_Pad_D1.0mm
U1: IS31FL3741A-QFLS4-TR; QFN-60_L7.0-W7.0-P0.40-TL-EP5.3; LCSC Part C2940604
U2, U3: HC-1.0-4PWT-B-HW; CONN-SMD_4P-P1.00_HCTL_HC-1.0-4PWT; LCSC Part C19270571
U4, U5, U6, U7: BTC-3215-BN02; SMD-1_L3.0-W2.0-H1.5; LCSC Part C34373670

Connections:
3V3: JP1.1 (A), U2.2, U3.2
CS1: R1.1, U1.26 (CS1)
CS2: R2.1, U1.27 (CS2)
CS3: R3.1, U1.28 (CS3)
CS4: R6.1, U1.29 (CS4)
CS5: R5.1, U1.30 (CS5)
CS6: R4.1, U1.31 (CS6)
CS7: R9.1, U1.32 (CS7)
CS8: R8.1, U1.33 (CS8)
CS9: R7.1, U1.34 (CS9)
CS10: R18.1, U1.35 (CS10)
CS11: R17.1, U1.37 (CS11)
CS12: R16.1, U1.38 (CS12)
CS13: R15.1, U1.39 (CS13)
CS14: R14.1, U1.40 (CS14)
CS15: R13.1, U1.41 (CS15)
CS16: R12.1, U1.42 (CS16)
CS17: R11.1, U1.43 (CS17)
CS18: R10.1, U1.44 (CS18)
CS19: R27.1, U1.45 (CS19)
CS20: R26.1, U1.46 (CS20)
CS21: R25.1, U1.47 (CS21)
CS22: R24.1, U1.48 (CS22)
CS23: R23.1, U1.49 (CS23)
CS24: R22.1, U1.50 (CS24)
CS25: R21.1, U1.51 (CS25)
CS26: R20.1, U1.52 (CS26)
CS27: R19.1, U1.53 (CS27)
CS28: R36.1, U1.54 (CS28)
CS29: R35.1, U1.56 (CS29)
CS30: R34.1, U1.57 (CS30)
CS31: R33.1, U1.58 (CS31)
CS32: R32.1, U1.59 (CS32)
CS33: R31.1, U1.60 (CS33)
CS34: R30.1, U1.1 (CS34)
CS35: R29.1, U1.2 (CS35)
CS36: R28.1, U1.3 (CS36)
CS37: R39.1, U1.4 (CS37)
CS38: R38.1, U1.5 (CS38)
CS39: R37.1, U1.6 (CS39)
GND: C1.2, C2.2, C3.2, C4.2, C5.2, C6.2, C7.2, C8.2, C9.2, C10.2, C11.2, CN1.2, CN1.3, CN1.4, CN2.2, CN2.3, CN2.4, CN5.8, CN5.10, CN5.12, CN5.14, CN5.16, CN5.18, CN5.20, CN5.22, CN5.24, CN5.26, CN5.28, CN5.30, CN5.32, CN5.34, CN5.36, CN5.38, CN5.40, CN6.10, CN6.12, CN6.14, CN6.17, CN6.19, CN6.21, CN6.23, CN6.27, CN6.29, CN6.31, R41.1, R42.2, TP2.1, U1.12 (GND), U1.36 (GND), U1.55 (GND), U1.61 (EP), U2.1, U2.5, U2.6, U3.1, U3.5, U3.6, U4.1, U5.1, U6.1, U7.1
INTB: TP3.1, U1.7 (INTB)
unnamed: R42.1, R43.1, R44.1, R45.1, U1.8 (ADDR)
unnamed: R41.2, U1.13 (ISET)
S1: CN6.13, R1.2
S2: CN6.11, R2.2
S3: CN6.9, R3.2
S4: CN6.2, R6.2
S5: CN6.4, R5.2
S6: CN6.8, R4.2
S7: CN6.40, R9.2
S8: CN6.38, R8.2
S9: CN6.33, CN6.34, R7.2
S10: CN6.32, R18.2
S11: CN6.30, R17.2
S12: CN6.28, R16.2
S13: CN6.24, R15.2
S14: CN6.22, R14.2
S15: CN6.20, R13.2
S16: CN6.18, R12.2
S17: CN5.39, R11.2
S18: CN5.37, R10.2
S19: CN5.35, R27.2
S20: CN5.33, R26.2
S21: CN5.31, R25.2
S22: CN5.29, R24.2
S23: CN5.27, R23.2
S24: CN5.25, R22.2
S25: CN5.23, R21.2
S26: CN5.21, R20.2
S27: CN5.19, R19.2
S28: CN5.17, R36.2
S29: CN5.15, R35.2
S30: CN5.13, R34.2
S31: CN5.11, R33.2
S32: CN5.9, R32.2
S33: CN5.7, R31.2
S34: CN5.5, R30.2
S35: CN5.3, R29.2
S36: CN5.1, R28.2
S37: CN5.2, R39.2
S38: CN5.4, R38.2
S39: CN5.6, R37.2
SCL: R43.2, U1.10 (SCL), U2.4, U3.4
SDA: R44.2, U1.9 (SDA), U2.3, U3.3
SDB: C7.1, R40.2, TP1.1, U1.11 (SDB)
SW1: CN6.7, U1.16 (SW1)
SW2: CN6.3, U1.17 (SW2)
SW3: CN6.1, U1.18 (SW3)
SW4: CN6.5, CN6.6, U1.19 (SW4)
SW5: CN6.15, CN6.16, U1.20 (SW5)
SW6: CN6.25, CN6.26, U1.21 (SW6)
SW7: CN6.35, CN6.36, U1.22 (SW7)
SW8: CN6.39, U1.23 (SW8)
SW9: CN6.37, U1.24 (SW9)
VCC: C1.1, C2.1, C3.1, C4.1, C5.1, C6.1, C8.1, C9.1, C10.1, C11.1, CN1.1, CN2.1, JP1.2 (B), R40.1, R45.2, U1.14 (AVCC), U1.15 (PVCC), U1.25 (PVCC)

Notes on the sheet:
ADDR
CONNECTORS
POWER CONNECTORS (2.7V-5.5V)
3V3 -> VCC JUMPER
SHUTDOWN PIN (CONNECT TO GND TO SHUT DOWN)
INTERRUPT PIN (USE EXTERNAL PULL UP IF IN USE)
GND VCC SCL SDA
0x00 0x11 0x01 0x10
I2C Address

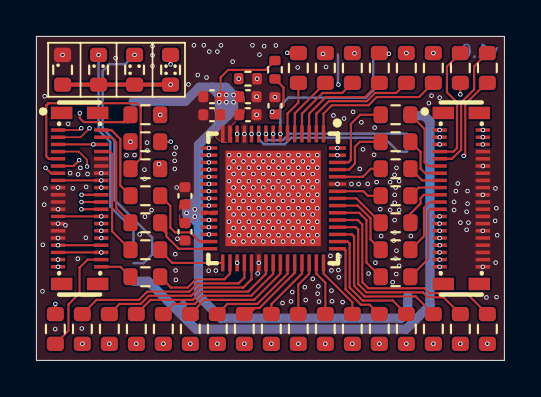
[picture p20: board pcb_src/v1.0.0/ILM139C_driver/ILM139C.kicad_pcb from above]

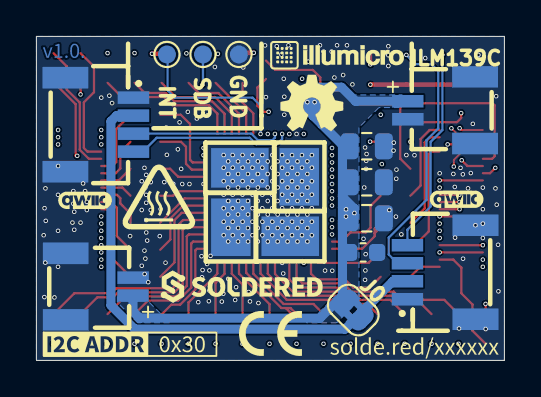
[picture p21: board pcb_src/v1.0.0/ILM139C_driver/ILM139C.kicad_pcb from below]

Board: 4 copper layers, 26.0 x 18.0 mm, 73 parts (18 on the bottom side), 96 nets.

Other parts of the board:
kibuzzard-68774F71: G***; kibuzzard-68774F71
kibuzzard-687750FB: G***; kibuzzard-687750FB

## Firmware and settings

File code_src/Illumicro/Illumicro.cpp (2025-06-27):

#include "Illumicro.h"

// LED mapping table: ILM139C[row][led], row=0-8, led=0-38 (13 pixels × 3 colors)
const uint8_t Illumicro::ILM139C[9][39] =
{
  {
    0x00,0x01,0x02,0x03,0x04,0x05,0x06,0x07,0x08,0x09,0x0A,0x0B,0x0C,0x0D,0x0E,0x0F,0x10,0x11,0x12,0x13,0x14,0x15,0x16,0x17,0x18,0x19,0x1A,0x1B,0x1C,0x1D,0x5A,0x5B,0x5C,0x5D,0x5E,0x5F,0x60,0x61,0x62
  },
  {
    0x1E,0x1F,0x20,0x21,0x22,0x23,0x24,0x25,0x26,0x27,0x28,0x29,0x2A,0x2B,0x2C,0x2D,0x2E,0x2F,0x30,0x31,0x32,0x33,0x34,0x35,0x36,0x37,0x38,0x39,0x3A,0x3B,0x63,0x64,0x65,0x66,0x67,0x68,0x69,0x6A,0x6B
  },
  {
    0x3C,0x3D,0x3E,0x3F,0x40,0x41,0x42,0x43,0x44,0x45,0x46,0x47,0x48,0x49,0x4A,0x4B,0x4C,0x4D,0x4E,0x4F,0x50,0x51,0x52,0x53,0x54,0x55,0x56,0x57,0x58,0x59,0x6C,0x6D,0x6E,0x6F,0x70,0x71,0x72,0x73,0x74
  },
  {
    0x5A,0x5B,0x5C,0x5D,0x5E,0x5F,0x60,0x61,0x62,0x63,0x64,0x65,0x66,0x67,0x68,0x69,0x6A,0x6B,0x6C,0x6D,0x6E,0x6F,0x70,0x71,0x72,0x73,0x74,0x75,0x76,0x77,0x75,0x76,0x77,0x78,0x79,0x7A,0x7B,0x7C,0x7D
  },
  {
    0x78,0x79,0x7A,0x7B,0x7C,0x7D,0x7E,0x7F,0x80,0x81,0x82,0x83,0x84,0x85,0x86,0x87,0x88,0x89,0x8A,0x8B,0x8C,0x8D,0x8E,0x8F,0x90,0x91,0x92,0x93,0x94,0x95,0x7E,0x7F,0x80,0x81,0x82,0x83,0x84,0x85,0x86
  },
  {
    0x96,0x97,0x98,0x99,0x9A,0x9B,0x9C,0x9D,0x9E,0x9F,0xA0,0xA1,0xA2,0xA3,0xA4,0xA5,0xA6,0xA7,0xA8,0xA9,0xAA,0xAB,0xAC,0xAD,0xAE,0xAF,0xB0,0xB1,0xB2,0xB3,0x87,0x88,0x89,0x8A,0x8B,0x8C,0x8D,0x8E,0x8F
  },
  {
    0x00,0x01,0x02,0x03,0x04,0x05,0x06,0x07,0x08,0x09,0x0A,0x0B,0x0C,0x0D,0x0E,0x0F,0x10,0x11,0x12,0x13,0x14,0x15,0x16,0x17,0x18,0x19,0x1A,0x1B,0x1C,0x1D,0x90,0x91,0x92,0x93,0x94,0x95,0x96,0x97,0x98
  },
  {
    0x1E,0x1F,0x20,0x21,0x22,0x23,0x24,0x25,0x26,0x27,0x28,0x29,0x2A,0x2B,0x2C,0x2D,0x2E,0x2F,0x30,0x31,0x32,0x33,0x34,0x35,0x36,0x37,0x38,0x39,0x3A,0x3B,0x99,0x9A,0x9B,0x9C,0x9D,0x9E,0x9F,0xA0,0xA1
  },
  {
    0x3C,0x3D,0x3E,0x3F,0x40,0x41,0x42,0x43,0x44,0x45,0x46,0x47,0x48,0x49,0x4A,0x4B,0x4C,0x4D,0x4E,0x4F,0x50,0x51,0x52,0x53,0x54,0x55,0x56,0x57,0x58,0x59,0xA2,0xA3,0xA4,0xA5,0xA6,0xA7,0xA8,0xA9,0xAA
  }
};

Illumicro::Illumicro(uint8_t addr)
  : _addr(addr), _gcc(32)
{
}

void Illumicro::begin()
{
  Wire.begin();
  Wire.setClock(1000000);
  selectPage(4);
  writeReg(0x3F, 0xAE); // Reset
  writeReg(0x00, 0x01); // Normal operation
  writeReg(0x01, _gcc); // GCC = 127
  writeReg(0x02, 0x55); // 8kΩ pull resistors
  writeTwoPages(2, 32); // Default scaling
}

void Illumicro::setLED(uint8_t row, uint8_t col, uint8_t color, uint8_t pwm)
{
  if (row > 8 || col > 12 || color > 2)
    return;
  uint8_t addr = ILM139C[row][col * 3 + color];
  int8_t page;
  if (row >= 6 || col >= 10)
  {
    page = 1;
  }
  else
  {
    page = 0;
  }
  selectPage(page);
  writeReg(addr, pwm);
}

void Illumicro::setGCC(uint8_t gcc)
{
  _gcc = gcc;
  selectPage(4);
  writeReg(0x01, _gcc);
}

void Illumicro::setGlobalMaxCurrentPercent(uint8_t percent, uint16_t r_iset)
{
  if (percent > 100 || r_iset == 0)
    return;
  uint8_t sl = (uint16_t)(percent * 255) / 100;
  writeTwoPages(2, sl);
}

void Illumicro::setLEDMaxCurrent(uint8_t row, uint8_t col, uint8_t color, float current_mA, uint16_t r_iset)
{
  if (row > 8 || col > 12 || color > 2 || current_mA <= 0 || r_iset == 0)
    return;
  float alpha = (255.0 / 256.0) * (1.0 / 10.125);
  float i_out_peak = current_mA / alpha;
  float sl_float = i_out_peak * 256.0 * r_iset / (383.0 * (_gcc / 256.0));
  uint8_t sl = min(max(static_cast<int>(sl_float + 0.5), 0), 255);
  uint8_t addr = ILM139C[row][col * 3 + color];
  uint8_t page;
  if (row >= 6 || col >= 10)
  {
    page = 1;
  }
  else
  {
    page = 0;
  }
  selectPage(page);
  writeReg(addr, sl);
}

void Illumicro::pushFrame(uint8_t frame[9][13][3])
{
  uint8_t buffer[351] = {0};
  for (uint8_t row = 0; row < 9; row++)
  {
    for (uint8_t col = 0; col < 13; col++)
    {
      for (uint8_t color = 0; color < 3; color++)
      {
        uint8_t addr = ILM139C[row][col * 3 + color];
        uint8_t page;
        if (row >= 6 || col >= 10)
        {
          page = 1;
        }
        else
        {
          page = 0;
        }
        uint16_t buffer_index = (page == 0) ? addr : (180 + addr);
        buffer[buffer_index] = frame[row][col][color];
      }
    }
  }
  writeBlock(0, 0x00, buffer, 180);
  writeBlock(1, 0x00, buffer + 180, 171);
}

uint8_t Illumicro::getRegisterAddress(uint8_t row, uint8_t col, uint8_t color)
{
  if (row > 8 || col > 12 || color > 2)
    return 0;
  return ILM139C[row][col * 3 + color];
}

void Illumicro::demo()
{
  for (uint8_t step = 0; step < 200; step++)
  {
    uint8_t offset = step * 5;
    for (uint8_t row = 0; row < 9; row++)
    {
      for (uint8_t col = 0; col < 13; col++)
      {
        uint8_t h = (row * 28 + col * 20 + offset) % 255;
        uint8_t r, g, b;
        hsvToRgb(h, 255, 255, r, g, b);
        setLED(row, col, 0, b);
        setLED(row, col, 1, g);
        setLED(row, col, 2, r);
      }
    }
    delay(50);
  }
}

void Illumicro::demoBreathing()
{
  for (uint8_t row = 0; row < 9; row++)
  {
    for (uint8_t col = 0; col < 13; col++)
    {
      setLED(row, col, 0, 255);
      setLED(row, col, 1, 255);
      setLED(row, col, 2, 255);
    }
  }
  for (uint8_t step = 0; step < 200; step++)
  {
    float angle = (PI * step) / 200.0;
    uint8_t percent = (uint8_t)(sin(angle) * sin(angle) * 100.0);
    setGlobalMaxCurrentPercent(percent, 2550);
    delay(10);
  }
  for (uint8_t row = 0; row < 9; row++)
  {
    for (uint8_t col = 0; col < 13; col++)
    {
      setLED(row, col, 0, 0);
      setLED(row, col, 1, 0);
      setLED(row, col, 2, 0);
    }
  }
}

void Illumicro::hsvToRgb(uint8_t h, uint8_t s, uint8_t v, uint8_t &r, uint8_t &g, uint8_t &b)
{
  if (s == 0)
  {
    r = v;
    g = v;
    b = v;
    return;
  }
  uint8_t region = h / 43;
  uint8_t remainder = (h - (region * 43)) * 6;
  uint8_t p = (v * (255 - s)) >> 8;
  uint8_t q = (v * (255 - ((s * remainder) >> 8))) >> 8;
  uint8_t t = (v * (255 - ((s * (255 - remainder)) >> 8))) >> 8;
  switch (region)
  {
    case 0:
      r = v;
      g = t;
      b = p;
      break;
    case 1:
      r = q;
      g = v;
      b = p;
      break;
    case 2:
      r = p;
      g = v;
      b = t;
      break;
    case 3:
      r = p;
      g = q;
      b = v;
      break;
    case 4:
      r = t;
      g = p;
      b = v;
      break;
    default:
      r = v;
      g = p;
      b = q;
      break;
  }
}

void Illumicro::unlock()
{
  Wire.beginTransmission(_addr);
  Wire.write(0xFE);
  Wire.write(0xC5);
  Wire.endTransmission();
}

void Illumicro::selectPage(uint8_t page)
{
  unlock();
  Wire.beginTransmission(_addr);
  Wire.write(0xFD);
  Wire.write(page);
  Wire.endTransmission();
}

void Illumicro::writeReg(uint8_t reg, uint8_t val)
{
  Wire.beginTransmission(_addr);
  Wire.write(reg);
  Wire.write(val);
  Wire.endTransmission();
}
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

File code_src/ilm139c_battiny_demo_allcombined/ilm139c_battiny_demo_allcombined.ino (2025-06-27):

#include <Illumicro.h>
#include <Arduino.h>

// Constants
const int ROWS = 9;
const int COLS = 13;
const int BUTTON_PIN = PIN_PA7;

// Digit patterns for 0-9 (3x5 pixels) for trailing demo FPS display
const uint8_t digit_patterns[10][5][3] = {
  {{1,1,1}, {1,0,1}, {1,0,1}, {1,0,1}, {1,1,1}}, // 0
  {{0,1,0}, {0,1,0}, {0,1,0}, {0,1,0}, {0,1,0}}, // 1
  {{1,1,1}, {0,0,1}, {1,1,1}, {1,0,0}, {1,1,1}}, // 2
  {{1,1,1}, {0,0,1}, {1,1,1}, {0,0,1}, {1,1,1}}, // 3
  {{1,0,1}, {1,0,1}, {1,1,1}, {0,0,1}, {0,0,1}}, // 4
  {{1,1,1}, {1,0,0}, {1,1,1}, {0,0,1}, {1,1,1}}, // 5
  {{1,1,1}, {1,0,0}, {1,1,1}, {1,0,1}, {1,1,1}}, // 6
  {{1,1,1}, {0,0,1}, {0,1,0}, {1,0,0}, {1,0,0}}, // 7
  {{1,1,1}, {1,0,1}, {1,1,1}, {1,0,1}, {1,1,1}}, // 8
  {{1,1,1}, {1,0,1}, {1,1,1}, {0,0,1}, {1,1,1}}  // 9
};

// Star structure for starry night
struct Star {
  uint8_t row;
  uint8_t col;
  float phase;
};

// Global arrays
Star stars[20];
uint8_t frameBuffer[ROWS][COLS][3];

// Demo state
int currentDemo = 0;
unsigned long demoStartTime = 0;

Illumicro matrix(0x30); // Adjust I2C address if needed

void setup() {
  pinMode(PIN_PA6, OUTPUT);
  digitalWrite(PIN_PA6, HIGH);
  delay(500);

  pinMode(BUTTON_PIN, INPUT_PULLUP);

  matrix.begin();
  matrix.setGlobalMaxCurrentPercent(5, 2550);

  randomSeed(analogRead(0));

  // Initialize stars
  for (int i = 0; i < 20; i++) {
    stars[i].row = random(0, 9);
    stars[i].col = random(0, 13);
    stars[i].phase = random(0, 628) / 100.0;
  }

  // Clear matrix
  for (uint8_t row = 0; row < ROWS; row++) {
    for (uint8_t col = 0; col < COLS; col++) {
      matrix.setLED(row, col, 0, 0);
      matrix.setLED(row, col, 1, 0);
      matrix.setLED(row, col, 2, 0);
    }
  }
}

// Time-based demo functions
void wavyDemo() {
  const uint8_t baseline = 10; // Minimum LED intensity (10/255)
  for (uint8_t step = 0; step < 200; ++step) {
    float t = step * 0.05f; // Time in seconds (50ms per step)
    float color_angle = (2.0f * PI * step) / 200.0f; // Smooth color cycle over 10s
    uint8_t base_g = (uint8_t)(127.5f * (1.0f + sinf(color_angle))); // Green
    uint8_t base_b = (uint8_t)(127.5f * (1.0f + cosf(color_angle))); // Blue
    for (uint8_t row = 0; row < ROWS; ++row) {
      for (uint8_t col = 0; col < COLS; ++col) {
        float wave = 0.5f + 0.5f * sinf(2.0f * PI * (col / (float)COLS + t * 0.5f)); // Horizontal wave, moving up
        uint8_t intensity = (uint8_t)(wave * 245.0f) + baseline; // Scale to 245 + baseline
        if (intensity > 255) intensity = 255; // Clamp
        frameBuffer[row][col][0] = (base_b * intensity) >> 8; // Blue
        frameBuffer[row][col][1] = (base_g * intensity) >> 8; // Green
        frameBuffer[row][col][2] = (intensity * baseline) >> 8; // Dim red for contrast
      }
    }
    matrix.pushFrame(frameBuffer);
    delay(5);
  }
}

void diagonalWaveDemo() {
  for (uint8_t step = 0; step < 200; step++) {
    uint8_t offset = step % 26;
    for (uint8_t row = 0; row < ROWS; row++) {
      for (uint8_t col = 0; col < COLS; col++) {
        uint8_t diag = (row + col + offset) % 26;
        uint8_t r, g, b;
        if (diag < 8) { r = 255; g = 0; b = 0; }
        else if (diag < 16) { r = 0; g = 255; b = 0; }
        else { r = 0; g = 0; b = 255; }
        frameBuffer[row][col][0] = b;
        frameBuffer[row][col][1] = g;
        frameBuffer[row][col][2] = r;
      }
    }
    matrix.pushFrame(frameBuffer);
    delay(50);
  }
}

void pulseDemo() {
  const float center_row = (ROWS - 1) / 2.0f;
  const float center_col = (COLS - 1) / 2.0f;
  const uint8_t baseline = 10; // Minimum LED intensity (10/255)
  for (uint8_t step = 0; step < 200; ++step) {
    float t = step * 0.05f; // Time in seconds (50ms per step)
    float color_angle = (2.0f * PI * step) / 200.0f; // Smooth color cycle over 10s
    uint8_t base_r = (uint8_t)(127.5f * (1.0f + sinf(color_angle)));
    uint8_t base_g = (uint8_t)(127.5f * (1.0f + sinf(color_angle + 2.0f * PI / 3.0f)));
    uint8_t base_b = (uint8_t)(127.5f * (1.0f + sinf(color_angle + 4.0f * PI / 3.0f)));
    for (uint8_t row = 0; row < ROWS; ++row) {
      for (uint8_t col = 0; col < COLS; ++col) {
        float dx = col - center_col;
        float dy = row - center_row;
        float dist = sqrtf(dx * dx + dy * dy);
        float wave = 0.0f;
        for (int i = 0; i <= (int)(t / 1.0f); ++i) {
          float drop_time = t - i * 1.0f; // Time since drop i
          if (drop_time <= 3.0f) { // 3s for full matrix coverage
            for (int j = 0; j < 2; ++j) { // Two waves per drop
              float wave_time = drop_time - 0.2f * j;
              float wave_dist = dist - 3.5f * wave_time; // Wave speed: 3.5 pixels/sec
              if (wave_dist >= -0.8f && wave_dist <= 0.8f) {
                wave += 0.3f * (1.0f + cosf(PI * wave_dist)) * expf(-wave_time * 0.8f);
              }
            }
          }
        }
        uint8_t intensity = (uint8_t)(wave * 245.0f) + baseline; // Scale to 245 + baseline
        if (intensity > 255) intensity = 255; // Clamp
        frameBuffer[row][col][0] = (base_b * intensity) >> 8; // Blue
        frameBuffer[row][col][1] = (base_g * intensity) >> 8; // Green
        frameBuffer[row][col][2] = (base_r * intensity) >> 8; // Red
      }
    }
    matrix.pushFrame(frameBuffer);
    delay(5);
  }
}

void starryNight() {
  for (int s = 0; s < 500; s++) {
    memset(frameBuffer, 0, sizeof(frameBuffer));
    for (int i = 0; i < 20; i++) {
      float brightness = 255 * (0.5 + 0.5 * sin(millis() / 1000.0 + stars[i].phase));
      uint8_t b = (uint8_t)brightness;
      frameBuffer[stars[i].row][stars[i].col][0] = b;
      frameBuffer[stars[i].row][stars[i].col][1] = b;
      frameBuffer[stars[i].row][stars[i].col][2] = b;
    }
    matrix.pushFrame(frameBuffer);
    delay(20);
  }
}

void fallingSand() {
  struct Particle {
    uint8_t row;
    uint8_t col;
    uint8_t r;
    uint8_t g;
    uint8_t b;
  };

  Particle active[117];
  uint16_t active_count = 0;
  bool settled[9][13] = {0};
  uint16_t settled_count = 0;

  for (uint8_t row = 0; row < 9; row++) {
    for (uint8_t col = 0; col < 13; col++) {
      matrix.setLED(row, col, 0, 0);
      matrix.setLED(row, col, 1, 0);
      matrix.setLED(row, col, 2, 0);
    }
  }

  while (settled_count < 117) {
    if (active_count < 117) {
      uint8_t free_cols[13];
      uint8_t free_count = 0;
      for (uint8_t col = 0; col < 13; col++) {
        bool occupied = settled[0][col];
        for (uint8_t i = 0; i < active_count; i++) {
          if (active[i].row == 0 && active[i].col == col) {
            occupied = true;
            break;
          }
        }
        if (!occupied) {
          free_cols[free_count++] = col;
        }
      }
      if (free_count > 0) {
        uint8_t col = free_cols[random(0, free_count)];
        active[active_count].row = 0;
        active[active_count].col = col;
        active[active_count].r = random(0, 256);
        active[active_count].g = random(0, 63);
        active[active_count].b = random(0, 63);
        matrix.setLED(0, col, 0, active[active_count].b);
        matrix.setLED(0, col, 1, active[active_count].g);
        matrix.setLED(0, col, 2, active[active_count].r);
        active_count++;
      }
    }

    for (int i = 0; i < active_count; i++) {
      uint8_t row = active[i].row;
      uint8_t col = active[i].col;
      uint8_t r = active[i].r;
      uint8_t g = active[i].g;
      uint8_t b = active[i].b;

      if (row + 1 >= 9 || settled[row + 1][col]) {
        settled[row][col] = true;
        settled_count++;
        active[i] = active[active_count - 1];
        active_count--;
        i--;
      } else {
        bool can_move = true;
        for (int j = 0; j < active_count; j++) {
          if (j != i && active[j].row == row + 1 && active[j].col == col) {
            can_move = false;
            break;
          }
        }
        if (can_move) {
          matrix.setLED(row, col, 0, 0);
          matrix.setLED(row, col, 1, 0);
          matrix.setLED(row, col, 2, 0);
          active[i].row++;
          matrix.setLED(active[i].row, col, 0, b);
          matrix.setLED(active[i].row, col, 1, g);
          matrix.setLED(active[i].row, col, 2, r);
        }
      }
    }
    delay(50);
  }
  delay(1000); // Pause after completion
}

void loop() {
  // Time-based demos
  if (currentDemo == 0) {
    demoStartTime = millis();
    wavyDemo();
    currentDemo++;
  }
  else if (currentDemo == 1) {
    demoStartTime = millis();
    diagonalWaveDemo();
    currentDemo++;
  }
  else if (currentDemo == 2) {
    demoStartTime = millis();
    pulseDemo();
    currentDemo++;
  }
  else if (currentDemo == 3) {
    demoStartTime = millis();
    starryNight();
    currentDemo++;
  }
  else if (currentDemo == 4) {
    demoStartTime = millis();
    fallingSand();
    currentDemo++;
  }
  // Trailing demo
  else if (currentDemo == 5) {
    static float PARTICLE_SPEED = 20.0;
    static const float FADE_RATE = 1200.0;
    static bool ramp = true;
    static int particle_row = 0;
    static int particle_col = 0;
    static int state = 0;
    static unsigned long accumulated_time = 0;
    static unsigned long last_time = millis();
    static uint8_t brightness[ROWS][COLS] = {0};
    static unsigned long frame_count = 0;
    static unsigned long fps_start_time = last_time;
    static int fps = 0;

    unsigned long time_per_pixel = 1000 / PARTICLE_SPEED;
    unsigned long current_time = millis();
    unsigned long elapsed_time = current_time - last_time;
    last_time = current_time;
    accumulated_time += elapsed_time;
    frame_count++;

    if (current_time - fps_start_time >= 1000) {
      if ((PARTICLE_SPEED < 110) && (ramp == true)) {
        PARTICLE_SPEED += 10;
      } else {
        ramp = false;
      }
      if ((PARTICLE_SPEED > 20) && (ramp == false)) {
        PARTICLE_SPEED -= 10;
      } else {
        ramp = true;
      }
      fps = frame_count;
      frame_count = 0;
      fps_start_time = current_time;
    }
    

    for (int row = 0; row < ROWS; row++) {
      for (int col = 0; col < COLS; col++) {
        if (brightness[row][col] > 0) {
          int fade_amount = (FADE_RATE * elapsed_time) / 1000;
          brightness[row][col] = (brightness[row][col] > fade_amount) ? brightness[row][col] - fade_amount : 0;
        }
      }
    }

    while (accumulated_time >= time_per_pixel) {
      brightness[particle_row][particle_col] = 255;
      if (state == 0) {
        particle_col++;
        if (particle_col >= COLS - 1) { particle_col = COLS - 1; state = 1; }
      }
      else if (state == 1) {
        particle_row++;
        if (particle_row >= ROWS - 1) { particle_row = ROWS - 1; state = 2; }
      }
      else if (state == 2) {
        particle_col--;
        if (particle_col <= 0) { particle_col = 0; state = 3; }
      }
      else if (state == 3) {
        particle_row--;
        if (particle_row <= 0) { particle_row = 0; state = 0; }
      }
      accumulated_time -= time_per_pixel;
    }

    for (int row = 0; row < ROWS; row++) {
      for (int col = 0; col < COLS; col++) {
        if (row >= 2 && row <= 6 && col >= 2 && col <= 10) {
          int digit_index = (col - 2) / 3;
          int local_col = (col - 2) % 3;
          int local_row = row - 2;
          int digit_value;
          if (digit_index == 0) digit_value = fps / 100;
          else if (digit_index == 1) digit_value = (fps / 10) % 10;
          else digit_value = fps % 10;
          if (digit_patterns[digit_value][local_row][local_col] == 1) {
            frameBuffer[row][col][0] = 0;
            frameBuffer[row][col][1] = 45;
            frameBuffer[row][col][2] = 80;
          } else {
            frameBuffer[row][col][0] = 0;
            frameBuffer[row][col][1] = 0;
            frameBuffer[row][col][2] = 0;
          }
        } else {
          uint8_t b = brightness[row][col];
          if (row == particle_row && col == particle_col) {
            frameBuffer[row][col][0] = 55;
            frameBuffer[row][col][1] = 127;
            frameBuffer[row][col][2] = 255;
          } else {
            frameBuffer[row][col][0] = b / 10;
            frameBuffer[row][col][1] = 0;
            frameBuffer[row][col][2] = b / 10;
          }
        }
      }
    }
    matrix.pushFrame(frameBuffer);

    // Check for button press to restart
    if (digitalRead(BUTTON_PIN) == LOW) {
      delay(50); // Debounce
      if (digitalRead(BUTTON_PIN) == LOW) {
        currentDemo = 0;
        // Reset trailing demo state
        PARTICLE_SPEED = 20.0;
        ramp = true;
        particle_row = 0;
        particle_col = 0;
        state = 0;
        accumulated_time = 0;
        last_time = millis();
        memset(brightness, 0, sizeof(brightness));
        frame_count = 0;
        fps_start_time = last_time;
        fps = 0;
      }
    }
  }
}

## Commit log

2025-04-23 First board design
    [ILM139C-B_Cu.gbl, ILM139C-B_Mask.gbs, ILM139C-B_Paste.gbp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]
2025-04-24 Matrix design, visual
    [ILM139C.kicad_pcb, ILM139C.kicad_sch]
2025-04-25 Added 2x2 panel
    [ILM139C.kicad_sch]
2025-04-26 Added driver module
    [ILM139C.kicad_pcb, ILM139C.kicad_sch]
2025-04-26 QWIIC things added
    [ILM139C.kicad_pcb, ILM139C.kicad_sch]
2025-04-28 added docs
    [ILM139C-B_Cu.gbr, ILM139C-B_Mask.gbr, ILM139C-B_Paste.gbr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]
2025-05-06 Cleaned up, added images
    [ILM139C-B_Cu.gbl, ILM139C-B_Cu.gbr, ILM139C-B_Mask.gbr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]
2025-05-07 Added pinout, fixed qwiic
    [ILM139C.kicad_pcb, ILM139C.kicad_sch]
2025-05-10 Added production files
    [ILM139C-B_Cu.gbl, ILM139C-B_Cu.gbr, ILM139C-B_Mask.gbr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]
2025-06-27 Updated, added lib & demo code
    [ILM139C-B_Cu.gbl, ILM139C-B_Cu.gbr, ILM139C-B_Mask.gbr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]
2025-07-04 Updated to latest version
    [ILM139C-B_Cu.gbr, ILM139C-B_Mask.gbr, ILM139C-B_Paste.gbr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]
2025-07-18 Cleaned repo
    [ILM139C.kicad_pcb, ILM139C.kicad_sch, ILM139C_matrix_bom.csv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]
